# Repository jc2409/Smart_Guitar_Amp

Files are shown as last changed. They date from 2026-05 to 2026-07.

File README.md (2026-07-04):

# Smart Guitar Amp

Smart Guitar Amp Demo (https://www.youtube.com/watch?v=zBXpkTaCWV4)

A hybrid guitar-effect amplifier combining a hand-built analog signal chain, real-time
Arduino DSP firmware, and a browser-based control app. A player can dial in sounds
manually or describe a tone in natural language; the host translates that request into
validated firmware parameters and sends them to the board over USB serial.

Three working layers:

1. Analog hardware for guitar-level signal conditioning, optical gain control, ADC
   input conditioning, and PWM audio reconstruction.
2. Arduino firmware for real-time DSP, automatic gain control, serial commands, and
   telemetry.
3. A FastAPI + React web app with sliders, live telemetry, tuner display, OpenAI chat,
   and Whisper-based voice input.

The host falls back to a mock serial link when no board is connected, so the web app
and LLM/voice flow can be demonstrated without hardware.

## System Overview

```text
Guitar
  -> analog input buffer and 2.5 V bias
  -> optically controlled analog gain stage (VGA)
  -> 2nd-order Sallen-Key anti-aliasing LPF (fc = 7.2 kHz)
  -> Arduino A0 ADC (10-bit, 9615 Hz, free-running)
  -> ATmega328P DSP firmware (fixed-point, ISR-driven)
  -> 8-bit Fast PWM on pin 10 at 62.5 kHz
  -> two-stage RC reconstruction filter with op-amp buffer
  -> line / aux / high-impedance headphone output

Browser UI
  -> FastAPI host
  -> serial P frames to Arduino
  <- T telemetry frames from Arduino (~10 Hz)
  -> OpenAI chat and Whisper STT when enabled
```

The amp runs DSP on the bare-metal MCU; the browser, FastAPI host, and LLM steer
it over serial — without ever touching the real-time audio loop.

## Analog Signal Chain

The analog path runs entirely on a single 5 V rail. All audio rides a 2.5 V virtual
ground so the ATmega328P ADC sees a full bipolar swing without needing a split supply.

**Input stage — high-Z buffer and 2.5 V bias**

- R1 (10 kΩ) series input resistor gives a high-impedance front end (~MΩ with the
  op-amp) that will not load passive pickups.
- C1 (10 μF) AC-coupling cap blocks the guitar's DC, passing only the audio swing.
- A 2.5 V virtual-ground reference buffered by an LM358/MCP6002 (rail-to-rail,
  single-supply) centres the waveform for the ADC.

**Optocoupler VGA — silent analog gain control**

- The firmware drives an optocoupler LED from Timer1 PWM on pin 9 / OC1A.
- Light couples to an LDR (100 Ω–100 kΩ range), changing the analog gain without
  injecting any digital switching edges into the audio path.
- DC-free and click-free: resistance glides smoothly with no zipper noise or DC offset
  injection. Higher OCR1A = brighter LED = lower LDR resistance = lower gain.
- In automatic mode the firmware rides the VGA gently based on measured output peak:
  peak > 380 steps gain down, 8–40 steps gain up, < 8 (noise floor) never boosts,
  and silence drifts back to the resting value. One step per 15 ms gives a smooth
  ride with no pumping.

**Anti-alias filter and ADC**

- A 2nd-order Sallen-Key LPF (R = 10 kΩ, C = 2.2 nF, fc = 7.2 kHz) guards the ADC
  input. 7.2 kHz is well above the guitar's highest audible harmonic, so nothing
  musical is lost while aliasing is suppressed.
- ADC A0 runs free-running, prescaler 128 → ~9615 Hz sample rate (Nyquist 4.8 kHz).
- Prescaler 128 was chosen over 64: slower sampling doubles the 512-sample ring
  buffer's span to ~53 ms, maximising delay and reverb range, while 4.8 kHz Nyquist
  still covers the full guitar band.

**PWM audio output and reconstruction**

- Timer1 Mode 5 (8-bit Fast PWM, no prescaler) drives pin 10 / OC1B at 62.5 kHz.
- A two-stage passive RC chain (2.2 kΩ + 15 nF per pole) with an op-amp buffer between
  the stages attenuates the 62.5 kHz carrier by ~−44 dB while the guitar passband
  passes flat.
- The buffer-between-poles topology avoids the carrier feedthrough and slew-rate
  problems seen with a slow op-amp Sallen-Key stage.
- A 10 μF output coupling cap removes the 2.5 V DC bias; the HPF corner is ≈ 0.16 Hz,
  preserving full bass response. The output targets high-impedance line/aux inputs.
- 62.5 kHz was chosen so the carrier sits far above audio: a gentle two-pole passive
  RC can reject it fully. Trade-off: 10-bit→8-bit resolution (256 levels, ~48 dB SNR),
  which is adequate for guitar effects.

The PWM output-stage debugging and component choices are documented in
[src/PWM_Audio_Passthrough/DESIGN_NOTES.md](src/PWM_Audio_Passthrough/DESIGN_NOTES.md).

## Firmware

The current firmware is [src/DSP_Pipeline/DSP_Pipeline.ino](src/DSP_Pipeline/DSP_Pipeline.ino).
It targets an Arduino Uno R3 / ATmega328P.

**Real-time architecture**

Audio processing runs entirely in `ISR(ADC_vect)` — one DSP tick per sample at 9615 Hz
(~52 μs budget per sample). The ISR reads A0, subtracts the 2.5 V bias, runs one effect,
clips to ±511, shifts to 8-bit, and writes OCR1B. No float is used; every operation is
integer shifts and adds. Timer1's PWM hardware double-buffers OCR1B, so the 9615 Hz
ISR writes are glitch-free against the 62.5 kHz carrier.

Parameters are written by `loop()` atomically in a `cli/sei` block so the ISR never
reads a half-written parameter set. The 512-byte `int8_t` ring buffer holds ~53 ms
of history shared by delay, chorus, reverb, and tuner.

**Effects**

The firmware runs exactly one effect mode at a time:

| ID | Effect | Implemented behavior |
| --- | --- | --- |
| `0` | Clean | Transparent passthrough. |
| `1` | Overdrive | `driven = (x * drive) >> 4`, hard-clipped to ±511. `drive` 16 = edge of breakup, 180 = rock crunch, 480 = near square-wave metal. |
| `2` | Delay | One read-tap `delayLen` samples behind the write head; `feedback` regenerates the tail. Up to 512 samples (~53 ms slapback). |
| `3` | Chorus | Triangle-LFO modulated delay tap (depth 1–48 samples, rate 1–20 phase increments), 50/50 dry/wet, no feedback path. |
| `4` | Reverb | Ten fixed taps (73–487 samples, 7.6–50.7 ms) summed equally then fed back. Keep `feedback` < 205 for stability. |
| `5` | Tuner | Clean passthrough while `loop()` runs AMDF pitch detection every ~150 ms. |

**AMDF tuner**

The tuner computes D(τ) = Σ |buf[n] − buf[n+τ]| over lags τ = 24…128 samples
(≈ 75–400 Hz). Parabolic interpolation around the deepest dip recovers sub-sample
resolution — essential for the high strings, where one whole-sample lag step spans
tens of cents at 9615 Hz. A peak-amplitude gate suppresses readings on silence.
Pitch is reported as deci-Hz (Hz × 10) in the telemetry frame; the UI maps it to
the nearest standard-tuning string (E A D G B E) with a flat↔sharp cents needle.

**Serial control protocol**

The host sends an atomic all-parameters frame:

```text
P,<effect>,<drive>,<delayLen>,<feedback>,<mix>,<depth>,<rate>,<autoVGA>,<gain>
```

Ranges enforced by the firmware and host models:

| Field | Range | Meaning |
| --- | --- | --- |
| `effect` | 0-5 | Clean, overdrive, delay, chorus, reverb, tuner. |
| `drive` | 1-511 | Overdrive gain/clipping intensity. |
| `delayLen` | 1-512 | Delay tap distance in samples. |
| `feedback` | 0-255 | Delay repeats or reverb decay. |
| `mix` | 0-255 | Wet level for delay/reverb. |
| `depth` | 1-48 | Chorus modulation depth in samples. |
| `rate` | 1-20 | Chorus LFO phase increment. |
| `autoVGA` | 0 or 1 | Enable automatic analog gain control. |
| `gain` | -1 or 0-255 | `-1` keeps/uses auto mode; 0-255 sets manual VGA PWM. |

The board reports telemetry every 100 ms:

```text
T,<effect>,<peak>,<vga>,<clip>,<rxErr>,<freqDeciHz>
```

`freqDeciHz` is only nonzero in tuner mode and is reported as Hz × 10. The host turns
this into the tuner display against standard guitar tuning.

More firmware-specific notes are in [src/DSP_Pipeline/README.md](src/DSP_Pipeline/README.md).

## Web App

The web app lives in [src/host](src/host). It is a single FastAPI backend serving a
React/Vite frontend.

**Backend responsibilities**

- Own the real `AmpLink` serial connection, or use `MockLink` when hardware is absent.
- Keep the authoritative `AmpParams` state.
- Validate and clamp all values before they reach the firmware.
- Serve `GET /api/state`, `POST /api/params`, `POST /api/chat`, `POST /api/transcribe`,
  and `GET /api/telemetry`.
- Load `.env` for serial port, OpenAI proxy, CA bundle, model names, and server host/port.

**Frontend responsibilities**

- Manual amp controls for effect selection and the relevant parameters.
- Live telemetry and connection state.
- Tuner UI driven by firmware pitch telemetry.
- Chat panel for natural-language tone requests.
- Voice input flow using the wake phrase `hey amp`, browser microphone capture, Whisper
  transcription, and then the same chat/tone path as typed messages.

**Tone engine**

- OpenAI is the default provider when `OPENAI_API_KEY` is set.
- `OPENAI_BASE_URL` supports enterprise proxy routing.
- `OPENAI_CA_BUNDLE` lets Python trust enterprise TLS certificates without disabling
  verification.
- `OPENAI_CHAT_MODEL` currently defaults to `gpt-5.5`; change it in `.env` if the proxy
  reports no regional capacity for that model.
- Anthropic is available as a fallback with `AMP_LLM_PROVIDER=anthropic` and
  `ANTHROPIC_API_KEY`.

The LLM is not allowed to send arbitrary firmware strings. It can only call the structured
`set_amp_params` tool, and those values are validated by the host before the serial frame
is emitted.

## Running The Web App

From the repository root:

```bash
cd src/host
make env
# edit .env: set OPENAI_API_KEY, OPENAI_BASE_URL if required, and AMP_PORT if needed
make install
make run
```

Then open `http://127.0.0.1:8000`.

Useful setup commands:

```bash
make port          # list serial devices and mark likely Arduino ports
make set-port      # write detected board to .env as AMP_PORT=...
make serial-perms  # temporary Linux permission fix for the selected AMP_PORT
make doctor        # print local Python/Node/npm/OpenAI/AMP_PORT status
make web-dev       # frontend hot reload on :5173 while make run serves the API
make flash         # compile/upload firmware with arduino-cli
```

Dependencies and configuration are documented in [src/host/README.md](src/host/README.md).
The Python dependency lists are [src/host/requirements.txt](src/host/requirements.txt) and
[src/host/pyproject.toml](src/host/pyproject.toml); frontend dependencies are in
`src/host/web/package.json` and `src/host/web/package-lock.json`.

## Repository Layout

```text
data/                         images and schematics
src/DSP_Pipeline/             current Arduino DSP firmware and firmware README
src/PWM_Audio_Passthrough/    PWM output-stage prototype and final design notes
src/host/                     FastAPI backend, React frontend, Makefile, host docs
```

## Current Limitations

- Audio quality is constrained by the Arduino Uno ADC rate, 8-bit PWM output, SRAM, and
  simple reconstruction filter. This is a working guitar-effect prototype, not a studio
  audio interface.
- Only one firmware effect runs at a time (no chaining, e.g. overdrive + delay).
- The output stage expects a high-impedance input/load.
- Delay/reverb are limited to ~53 ms by the on-chip SRAM; external SRAM would extend this.
- Voice transcription and chat depend on the selected OpenAI model being available through
  the configured proxy and VPN policy.

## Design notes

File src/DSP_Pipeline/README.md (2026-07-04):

# Real-Time Guitar DSP Pipeline — Firmware

Arduino Uno R3 (ATmega328P) firmware implementing a real-time, **selectable
multi-effect** guitar DSP — **Clean / Overdrive / Delay / Chorus / Reverb** — plus
a **Tuner** mode that detects the played string's pitch, all with a serial command
interface for live parameter control.

Sketch: [`DSP_Pipeline.ino`](DSP_Pipeline.ino)

> **Note:** an earlier version of this firmware (and this README) ran a *cumulative*
> `Clip → Biquad EQ → Delay` pipeline driven by an `S,...` frame at 19230 Hz. That is
> obsolete. The current firmware selects **one** effect at a time and runs the ADC at
> **~9615 Hz**. The host software (`../host/`) targets this current protocol.

---

## Signal path

```
guitar (biased 2.5 V) ─▶ A0 ─▶ ADC (free-running, 10-bit, ~9.615 kHz, prescaler 128)
                                  │
                                  ▼  ISR(ADC_vect)   ← one DSP tick per sample
                    one of: Clean | Overdrive | Delay | Chorus | Reverb
                                  │
                                  ▼
                    OCR1B (8-bit, 62.5 kHz Fast PWM, pin 10)
                                  │
                                  ▼
                    RC reconstruction filter ─▶ analog audio out
```

- **Input**: guitar AC-coupled and biased to 2.5 V on A0; ADC reads 0..1023 (512 = silence).
- **Output**: pin 10 (OC1B), 8-bit Fast PWM, 62.5 kHz carrier, smoothed by an external RC filter.
- **Optocoupler**: pin 9 (OC1A), same Timer1, sets the analog VGA gain via the LED/LDR.
- **Sample rate**: ADC prescaler 128 → ~9615 Hz (Nyquist 4.8 kHz, matching the anti-alias LPF).
  Delay/reverb taps are `t = samples / 9615 Hz`; the 512-sample buffer holds ~53 ms.

---

## Effects

All processing is **fixed-point** (no float in the ISR). Samples are carried as
signed values centred on 0 (range −512..+511). **One effect is active at a time**
(selected with `e`); switching effects clears the audio ring buffer.

| ID | Effect | What it does | Parameters |
|----|---|---|---|
| 0 | **Clean** | Transparent passthrough | — |
| 1 | **Overdrive** | Pre-amplify then hard-clip | `thresh` 1..511 (drive: 16=breakup, 180=rock, 480=metal) |
| 2 | **Delay** | Single echo with feedback (~53 ms max) | `delayLen` 1..512, `feedback` 0..255, `mix` 0..255 |
| 3 | **Chorus** | Triangle-LFO modulated short delay, 50/50 dry/wet | `depth` 1..48, `rate` 1..20 |
| 4 | **Reverb** | Ten-tap feedback network | `feedback` 0..255 (keep < 205), `mix` 0..255 |
| 5 | **Tuner** | Clean passthrough + fundamental-pitch detection (reported via telemetry) | — |

**Delay/reverb timing**: `t = samples / 9615 Hz`. The 512-sample `int8` line holds ~53 ms.

### Tuner

Selecting **Tuner** (effect 5) passes the signal through clean while detecting the
played string's fundamental frequency and reporting it in the `freq` telemetry
field (deci-Hz; `0` = no pitch). The host UI shows the detected pitch against the
six standard-tuning strings (E2 A2 D3 G3 B3 E4) with a flat↔sharp cents needle.

- **Method**: **AMDF** (Average Magnitude Difference Function) over the audio ring
  buffer, searching lags ~24..128 samples (≈75–400 Hz). The deepest dip is the
  period; **parabolic interpolation** around it recovers sub-sample resolution —
  essential for the high strings, where one whole-sample lag step is tens of cents
  at 9615 Hz. A peak-amplitude gate suppresses readings on silence.
- **Where it runs**: in `loop()` (every ~150 ms), **not** the ISR, and only while
  effect 5 is active — so it costs nothing in the other modes. It works on a frozen
  copy of the most recent samples, since the ISR keeps overwriting the live ring
  during the (tens-of-ms) computation.

---

## Serial command interface

`115200 baud`, one command per line. The parser buffers a full line then parses
it (robust to `\n` / `\r\n` / no line ending).

| Command | Example | Effect |
|---|---|---|
| `e<0..5>` | `e1` | Select effect (0=clean 1=overdrive 2=delay 3=chorus 4=reverb 5=tuner) |
| `c<1..511>` | `c180` | Overdrive drive (thresh) |
| `d<1..512>` | `d400` | Delay length in samples |
| `f<0..255>` | `f190` | Delay/reverb feedback / decay |
| `m<0..255>` | `m220` | Delay/reverb wet mix |
| `r<1..48>` | `r24` | Chorus depth |
| `s<1..20>` | `s8` | Chorus LFO rate |
| `v<0\|1>` | `v1` | Auto-VGA on/off |
| `g<0..255>` | `g20` | Manual VGA gain (OCR1A); turns auto-VGA off |
| `x` | `x` | Bypass (clean passthrough) |
| `P,...` | `P,1,180,400,190,220,24,8,1,-1` | Atomic set-all frame (host link) |

The single-letter commands are for manual testing; the host uses the `P` frame.

> **Note**: a delay/echo is only audible on *transient* material (real guitar,
> plucks, music). On a steady sine it just produces inaudible comb filtering.

## Two-way host protocol (MCU ↔ PC)

Structured parameters in, status telemetry out. The host applies a whole preset
atomically with one `P` frame and reads `T` telemetry back:

```
PC -> MCU : P,<effect>,<drive>,<delayLen>,<feedback>,<mix>,<depth>,<rate>,<autoVGA>,<gain>\n
MCU -> PC : T,<effect>,<peak>,<vga>,<clip>,<rxErr>,<freq>\n      (emitted ~10 Hz)
```

- **`P` frame** — sets the entire parameter bank in one `cli/sei` section (no
  transient old+new mix), clearing the audio buffer on effect change. `gain` field
  `< 0` leaves the VGA untouched and honours the `autoVGA` flag; `>= 0` sets a manual
  gain and turns auto-VGA off. Malformed frames are rejected and counted in `rxErr`.
- **`T` telemetry** — `effect` (active effect ID), `peak` (max |output| since last
  report — a VU meter), `vga` (current `OCR1A`), `clip` (clipped since last report),
  `rxErr` (malformed-frame count), `freq` (detected fundamental in **deci-Hz** —
  Hz×10 — in tuner mode, else `0`).
  > The `freq` field is appended; the host parser accepts both the 6-field
  > (pre-tuner) and 7-field frames, so older firmware still parses.

### Host software

The full interface is the **web app** in [`../host/`](../host/) (FastAPI + LLM tone
engine + browser dashboard). For bench testing without a browser:

```bash
cd ../host && uv sync          # or: pip install -e .
python sf4_serial.py --demo overdrive
python sf4_serial.py --effect reverb --feedback 190 --mix 220
```

It builds a validated `AmpParams`, serialises the `P` frame, sends it, then prints
parsed `T` telemetry as a live meter.

---

## Architecture / timing

- **Timer1** — Mode 5, 8-bit Fast PWM, no prescaler → **62.5 kHz** carrier on
  OC1A (pin 9) and OC1B (pin 10). Pure hardware; **no overflow ISR**.
- **ADC** — free-running, `/128` prescaler → ~**9615 Hz** sample rate, with the
  conversion-complete interrupt enabled (Nyquist 4.8 kHz, matching the anti-alias LPF).
- **`ISR(ADC_vect)`** — the single DSP tick: reads `ADC`, runs `processEffect`,
  writes `OCR1B = result >> 2` (10-bit → 8-bit). Fires once per sample (~9615 Hz).
  Reading `ADC` clears `ADIF` and the ADC auto-restarts, so no flag handling is needed.
- `OCR1B` is **double-buffered** by the PWM hardware (latches at carrier BOTTOM),
  so updating it at 9615 Hz while the carrier runs at 62.5 kHz is glitch-free.
- **Parameter bank** — one `volatile Params` struct (`P`). `loop()` updates it
  atomically inside `noInterrupts()/interrupts()` (field-wise copies, because a
  `volatile` struct can't use the implicit copy ctor), so the ISR never reads a
  half-written parameter set.

---

## Testing & operation notes

### Reading the telemetry (`T,effect,peak,vga,clip,rxErr,freq`)
- **`effect`** — active effect ID (0–5).
- **`peak`** — loudest **post-effect** sample since the last report (~100 ms), as a
  centred magnitude. This is a live VU/level meter; it wobbles ±1 on a steady signal
  (normal). It reflects what the listener actually hears (the AGC rides off it), so
  it tracks the output, not the raw input.
- **`vga`** — current `OCR1A` (the optocoupler LED duty / analog gain); static until
  changed or moved by auto-VGA.
- **`clip`** — 1 if the signal hit the clip threshold in that window, else 0.
- **`rxErr`** — malformed-frame count; should stay 0 (link health).
- **`freq`** — detected fundamental in **deci-Hz** (Hz×10) in tuner mode, else `0`.

### Startup transient is expected (and repeats every run)
Opening the serial port toggles **DTR, which hardware-resets the Uno** — so every
`sf4_serial.py` run reboots the board from scratch. At boot `OCR1A = 20`
(resting VGA gain), then the first host `P` frame confirms auto-VGA mode; the optocoupler LDR
settles slowly (tens–hundreds of ms), so `peak` shows a brief spike that decays
(e.g. `197 → 6`). Harmless — it's the analog gain settling, not a glitch. Ignore
the first few telemetry lines, or add gain smoothing in firmware to remove it.

### What a sine-wave input can test
| Stage | Sine test | Method |
|---|---|---|
| Passthrough | ✅ | `x`; output = input, biased 2.5 V |
| Clipping (overdrive) | ✅ | drive above threshold → flat-topped wave + odd harmonics |
| Aliasing | ✅ | feed f > Nyquist (4.8 kHz) → watch it fold back |
| Delay comb | ✅ | sweep → notches every `FS/d` Hz |
| Chorus sweep | ✅ | slow LFO → pitch/comb notches drift up and down |
| Delay/reverb *echo* | ❌ | needs transients (real guitar / music) |
| Tuner | ✅ | feed a known tone → check `freq` (deci-Hz) telemetry |

### Signal levels (real guitar vs the VGA)
A raw passive guitar is weak and dynamic (~0.1–0.7 Vpp typical, peaks to ~1–1.5 Vpp
on hard strums, decaying fast) — it does **not** sit at line level. The optocoupler
**VGA (gain) is what boosts it** up to where `peak` crosses the clip threshold, so
`gain` (drive) + `clip_threshold` together behave like a pedal's Drive knob. On the
bench, ~1 Vpp from the generator is a *test* level to force clipping. Distortion is
naturally touch-sensitive: loud attack clips, decaying note cleans up.

---

## Implementation notes

### DSP runs in `ADC_vect`, not a timer ISR
The single DSP tick lives in **`ISR(ADC_vect)`** (~9615 Hz): it reads `ADC`, runs
`processEffect`, and writes `OCR1B`. The Timer1 overflow interrupt is left disabled
(`TIMSK1 = 0`) — the PWM carrier is pure hardware. Driving the DSP from the ADC
interrupt means it fires exactly once per sample, with no wasted firings.

### Atomic parameters from a `volatile` struct
`Params np = P;` / `P = np;` don't compile for a `volatile` struct, so `loop()`
copies fields one at a time inside `noInterrupts()/interrupts()`. This both satisfies
the compiler and makes parameter updates atomic — the ISR never sees a half-written
mix of old and new values, and switching effects clears the audio ring buffer.

### Robust serial parsing
The command parser **buffers a full line** then parses it with `atol` / `sscanf`,
tolerant of `\n`, `\r\n`, or no line ending. (An earlier `Serial.parseInt()` version
mis-read leftover `\r`/`\n` as `0`, e.g. `f160` → `feedback = 0`.) The board runs at
**115200 baud**; because the DSP no longer sits in a 62.5 kHz timer ISR, the USART RX
interrupt is serviced in time and there is no RX overrun.

### Two-way protocol (MCU ↔ PC)
The host applies a whole preset atomically with one **`P` frame** and reads **`T`
telemetry** back at ~10 Hz (`effect, peak, vga, clip, rxErr, freq`). The ISR tracks
`g_peak` / `g_clip` / `g_freqDeciHz`; `loop()` emits via `millis()`. The full
host-side link is the FastAPI web app in [`../host/`](../host/); `sf4_serial.py` is a
standalone CLI for bench testing the same `P`/`T` protocol.

---

## Recommended analog output stage

The PWM output needs an external reconstruction filter + buffer before any
external device. Drives high-impedance line inputs (Echo line-in, Sennheiser
Momentum 4 powered aux) directly — **no power amp needed**.

```
pin 10 ─[2-pole RC LPF: 2.2k / 15nF ×2]─ MCP6002 unity buffer ─ Rs 100Ω ─ Cout 10µF ─┬─ tip L ┐
                                                                                      ├─ tip R ┘ (tie, mono)
                                                                                     R 100k → GND
                                                                                      sleeve → GND
```

- **Use MCP6002** (rail-to-rail, single 5 V), **not** TL072 (needs ≥7 V).
- Because the MCP6002 is only 1 MHz GBW, **filter passively** (RC) and use the
  op-amp only as a buffer — do **not** put it in a Sallen-Key (it would leak the
  62.5 kHz carrier, like the LM358).
- Two RC poles give ~−40 dB at the carrier, removing the switching hash.
- `Cout` strips the 2.5 V DC bias; into a high-Z input the bass is preserved.

---

## Known limitations / potential issues

| Issue | Impact | Possible improvement |
|---|---|---|
| Hard-clip aliasing | Harsh "fizzy" distortion (folded harmonics) | Soft-clip lookup table; 2× oversampling |
| 8-bit PWM output | ~48 dB SNR; hiss on clean tones | Higher-res PWM; dithering |
| One effect at a time | No stacking (e.g. overdrive + delay) | Chain effects if CPU/SRAM allow |
| Delay/reverb ≤ ~53 ms | Slapback/short ambience, not long echo | External SRAM for a longer line |
| `int8` ring buffer | 2 LSBs dropped on stored samples | Wider buffer if SRAM allows |
| No parameter smoothing | Clicks on live LLM/host changes | Ramp parameters over a few ms |
| Free-running ADC jitter | Minor sample-timing noise | Timer-triggered ADC (needs a free timer) |
| 16 MHz AVR ceiling | Limited DSP headroom overall | Faster MCU for advanced effects |

---

## Status

Working lo-fi multi-effect demonstrator: selectable Clean / Overdrive / Delay /
Chorus / Reverb plus an AMDF Tuner, with live serial control **and a two-way MCU↔PC
link** (`P` params in, `T` telemetry out, at 115200). The FastAPI web app in
[`../host/`](../host/) drives this protocol from the browser, manual controls, and the
LLM tone engine; `sf4_serial.py` exercises the same link from the command line.

### Suggested next steps
- DSP quality: soft-clip lookup table (reduce overdrive aliasing), parameter/gain
  smoothing to remove clicks on live host changes.
- Longer delay/reverb via external SRAM, beyond the ~53 ms on-chip `int8` line.
- Build the MCP6002 analog output stage (above) for clean line-out.

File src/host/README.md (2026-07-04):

# Host - Backend, Voice UI, and Tone Engine

This directory contains the desktop/web host for the Smart Guitar Amp. One
FastAPI process owns the serial link to the Arduino, keeps the authoritative amp
state, runs the OpenAI-first tone engine, serves the React dashboard, and exposes
JSON/SSE APIs for manual control, chat, voice transcription, and telemetry.

## Layout

```text
app/
  main.py         FastAPI app: /api/* endpoints, static UI serving, app lifetime
  models.py       AmpParams, telemetry, chat schemas, firmware value ranges
  serial_link.py  hardware serial bridge, MockLink fallback, port autodetect
  tone_engine.py  OpenAI/Anthropic tone engine with set_amp_params tool use
  openai_client.py OpenAI client setup for API key, proxy URL, and CA bundle
  devtools.py     Makefile helpers for serial-port detection and config checks
  static/         built React UI generated by make web-build, gitignored
web/              React + Vite frontend source
sf4_serial.py     CLI bench-test tool for sending P frames and reading telemetry
Makefile          setup, build, run, serial, and firmware automation
requirements.txt  pip dependency list, kept in sync with pyproject.toml
pyproject.toml    Python project metadata and dependencies
.env.example      local configuration template; copy to .env
```

The React source lives in `web/`. `make web-build` compiles it into `app/static/`,
which FastAPI serves at `http://127.0.0.1:8000` by default.

## Quick Start

```bash
cd src/host
make env
# edit .env and set OPENAI_API_KEY, OPENAI_BASE_URL if using the Arm proxy,
# OPENAI_CA_BUNDLE if your machine needs the company CA, and SF4_PORT if needed
make install
make run
```

Open `http://127.0.0.1:8000`.

`make run` also installs Python dependencies and builds the UI on first run if the
built frontend is missing. Use `Ctrl+C` to stop Uvicorn.

## Make Targets

| Target | Purpose |
| --- | --- |
| `make help` | Print the available commands. |
| `make env` | Create `.env` from `.env.example` if it does not exist. |
| `make py-install` | Install backend dependencies with `uv sync` when `uv` is available, otherwise create `.venv` and run `pip install -r requirements.txt`. |
| `make web-install` | Install frontend dependencies with `npm ci --include=dev --no-audit --no-fund --progress=false`. |
| `make web-build` | Build the React/Vite UI into `app/static/`. |
| `make install` | Run backend install, frontend install, and frontend build. |
| `make run` | Start FastAPI on `HOST:PORT`, building the UI first if missing. |
| `make dev` | Same as `make run`, but with Uvicorn `--reload`. |
| `make web-dev` | Start Vite hot reload on port 5173; `/api` is proxied to FastAPI on port 8000. |
| `make port` | List detected serial ports and mark likely Arduino ports with `*`. |
| `make set-port` | Write the first likely Arduino port into `.env` as `SF4_PORT=...`. |
| `make serial-perms` | Temporarily run `sudo chmod a+rw $(SF4_PORT)` if Linux denies access to the board. |
| `make doctor` | Print Python, Node, npm, host URL, serial setting, and whether OpenAI settings are present. |
| `make cli ARGS="--demo overdrive"` | Test the serial link without the browser. |
| `make flash` | Compile and upload `../DSP_Pipeline` with `arduino-cli`. |
| `make clean` | Remove `.venv`, Python caches, and built UI output. |

For frontend-only development, use two terminals:

```bash
make run        # terminal A: FastAPI on :8000
make web-dev    # terminal B: Vite on :5173 with /api proxying
```

## Dependencies

System tools:

- Python 3.11 or newer.
- Node.js and npm for the React/Vite frontend.
- `arduino-cli` only if you want `make flash` to compile and upload firmware.
- Linux serial access to the board, either through group membership or `make serial-perms`.

Python packages are declared in both `requirements.txt` and `pyproject.toml`:

- `fastapi`, `uvicorn[standard]`: web server and API runtime.
- `pyserial`: USB serial link to the Arduino.
- `openai`, `httpx`: OpenAI chat/STT client, enterprise proxy, and CA-bundle support.
- `anthropic`: optional fallback provider.
- `pydantic`: API and firmware parameter validation.
- `python-dotenv`: `.env` loading.
- `python-multipart`: browser audio upload support for `/api/transcribe`.

Frontend packages are managed by `web/package.json` and `web/package-lock.json`.
Use `make web-install` or `make install`; do not use `npm install --omit=dev`, because
Vite is a dev dependency required for building.

## Configuration

Copy `.env.example` to `.env` with `make env`. `.env` is gitignored and should hold
machine-specific settings and API keys.

| Variable | Default | Meaning |
| --- | --- | --- |
| `SF4_LLM_PROVIDER` | `openai` | Tone engine provider: `openai` or `anthropic`. |
| `OPENAI_API_KEY` | blank | Required for OpenAI chat and Whisper transcription. |
| `OPENAI_CHAT_MODEL` | `gpt-5.5` | Chat model used for tone generation. Change this if the proxy has no capacity for that model. |
| `OPENAI_BASE_URL` | OpenAI default | Set to the enterprise proxy URL, for example `https://openai-api-proxy.geo.arm.com/api/providers/openai/v1`. |
| `OPENAI_CA_BUNDLE` | Arm root CA path | Optional CA bundle path for enterprise TLS verification. |
| `OPENAI_TRANSCRIBE_MODEL` | `whisper-1` | Speech-to-text model used by `/api/transcribe`. |
| `ANTHROPIC_API_KEY` | blank | Optional fallback when `SF4_LLM_PROVIDER=anthropic`. |
| `SF4_MODEL` | `claude-haiku-4-5` | Anthropic model name for the fallback provider. |
| `SF4_PORT` | auto-detect | Serial device, for example `/dev/ttyACM0`. Use `make port` or `make set-port`. |
| `HOST` / `PORT` | `127.0.0.1` / `8000` | Uvicorn bind address used by `make run` and `make dev`. |

For the Arm enterprise OpenAI proxy, the relevant `.env` entries are usually:

```bash
OPENAI_API_KEY=your_key_here
OPENAI_BASE_URL=https://openai-api-proxy.geo.arm.com/api/providers/openai/v1
OPENAI_CA_BUNDLE=/usr/local/share/ca-certificates/ARM-Enterprise-PKI-Root-CA.crt
OPENAI_CHAT_MODEL=gpt-5.5
OPENAI_TRANSCRIBE_MODEL=whisper-1
```

If you see `data_residency_mismatch` or `No available capacity`, the proxy rejected the
selected model in that region. Change `OPENAI_CHAT_MODEL` to a model that your proxy
supports and restart `make run`.

## API

| Endpoint | Purpose |
| --- | --- |
| `GET /api/state` | Current amp parameters, serialized with the effect name. |
| `POST /api/params` | Apply a full manual `AmpParams` update. |
| `POST /api/chat` | Run one tone-engine turn; may call `set_amp_params` and update the board. |
| `POST /api/transcribe` | Upload browser audio and return Whisper text. |
| `GET /api/telemetry` | Server-Sent Events stream of board telemetry at about 10 Hz. |

The app falls back to `MockLink` when no Arduino is available, so the UI, chat, and
voice flow can be tested without hardware. Manual changes still update the shared app
state, but no serial frames are sent to a board.

## Troubleshooting

- `vite: not found`: run `make web-install` or `make install`. If npm used omitted dev dependencies, run `npm --prefix web ci --include=dev --no-audit --no-fund --progress=false`.
- Npm hangs on VPN: check whether company VPN/proxy rules block `registry.npmjs.org`; disconnecting VPN or configuring npm proxy may be required.
- `Permission denied: /dev/ttyACM0`: run `make set-port`, then `make serial-perms`, or add your user to the Linux dialout group and log out/in.
- `Chat is unavailable`: set `OPENAI_API_KEY` or configure the Anthropic fallback, then restart the server.
- `Transcription error`: check `OPENAI_API_KEY`, `OPENAI_BASE_URL`, `OPENAI_CA_BUNDLE`, and VPN/proxy connectivity.
- Browser says microphone denied: allow microphone access for `http://127.0.0.1:8000` in the browser site settings, then reload.

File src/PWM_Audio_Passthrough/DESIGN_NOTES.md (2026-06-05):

# PWM Audio Passthrough — Design & Debug Notes

A record of the debugging session that took the PWM audio output from "looks like
raw PWM on the scope" to a clean, full-range guitar signal. Covers the filter
diagnosis, the component-value fixes, and the firmware change to a 62.5 kHz carrier.

---

## 1. The system

- **Arduino Uno R3**, guitar signal biased to 2.5 V into **A0** (ADC 0..1023, 512 ≈ silence).
- **Timer1 Fast PWM** drives two independent outputs:
  - **Pin 10 (OC1B)** → audio, through a low-pass filter → audio jack.
  - **Pin 9 (OC1A)** → optocoupler LED (VGA gain stage), set over serial.
- Audio recovered by averaging the PWM (low-pass) then AC-coupling out (high-pass).

Output analog chain (KiCad): `pin 10 → R12 → C7 (low-pass) → LM358 (U2B) → C8 → R13 (high-pass) → AudioJack`.

---

## 2. The symptom

On the PicoScope:
- **Blue (A)** = analog input at A0: a clean sine (300/600/800 Hz test tones), biased at 2.5 V.
- **Red (B)** = "recovered" output: a dense band of pulses, **cycle time 64.00 µs → 15.625 kHz**.

The red trace never looked like the blue sine. The user asked why.

### Why red ≠ blue (the concept)
The raw PWM is a **two-level carrier** (≈0 V or ≈5 V) switching at 15.625 kHz. The
audio is encoded in the **duty cycle / pulse width**, not the instantaneous voltage:

```
blue high (3.5V)  ->  OCR1B large  ->  pulses WIDE  (more time at 5V)
blue low  (2.0V)  ->  OCR1B small  ->  pulses NARROW (more time at 0V)
```

You recover the sine by taking the **running average** of the PWM — which is exactly
what the RC low-pass does. So red ≠ blue *before* the filter is expected and correct.

---

## 3. Root cause #1 — the low-pass filter wasn't filtering

A low-pass needs **both** the series resistor **and** the shunt cap to ground. R12
alone does nothing (the op-amp input is high-impedance, so almost no drop across R12).
C7 is the part that averages the pulses.

The cutoff:

$$f_c = \frac{1}{2\pi R C}$$

The board had **R12 = 1k** and **C7 marked `103` = 10 nF** (NOT the assumed 220 nF):

$$f_c = \frac{1}{2\pi \cdot 1000 \cdot 10\text{n}} \approx 15.9\ \text{kHz}$$

That sits **right on top of the 15.625 kHz carrier** → only −3 dB attenuation → the
carrier passes straight through. Time-constant view: `τ = R12·C7 = 10 µs`, but the
PWM period is `64 µs`, so the cap fully tracks each pulse instead of averaging.

### Capacitor code reminder (value in picofarads)
| Code | Value | Notes |
|---|---|---|
| `103` | 10 nF | what was in C7 (wrong — too small) |
| `104` | 100 nF | fc ≈ 1.6 kHz |
| `224` | 220 nF | fc ≈ 723 Hz |

> The user *thought* 220 nF was in C7, but `224` (220 nF) was actually in **C8**
> (the output coupling cap). So C7 = 10 nF (low-pass), C8 = 220 nF (coupling) —
> swapped roles.

### Fix
Put a real **220 nF (`224`)** in C7. With R12 = 1k → fc ≈ 723 Hz, carrier ≈ −27 dB.
The red trace then collapsed into a recognizable sine (with some residual ripple).

---

## 4. Root cause #2 — single RC can't cover guitar range AND reject the carrier

After the 220 nF fix, the recovered sine still had **high-frequency ripple** (residual
15.6 kHz carrier). The fundamental problem:

- **Guitar needs audio out to ~5 kHz** (fundamentals reach ~1.3 kHz; harmonics/tone to ~5–6 kHz).
- **Carrier is at 15.6 kHz** — only **~3× above** the audio top.
- A single-pole RC is just 20 dB/decade. To kill a carrier only 3× away you must drop
  fc so low it also eats the guitar harmonics. **You can't win with a filter alone.**

Single-pole trade-off table (R12 = 1k):

| C7 | Code | fc | Carrier rejection | Audio bandwidth |
|----|---|----|----|----|
| 220 nF | `224` | 723 Hz | −27 dB (~150 mV ripple) | ~720 Hz |
| 470 nF | `474` | 339 Hz | −33 dB | ~340 Hz (too dull) |
| 1 µF | `105` | 159 Hz | −40 dB | bass only ❌ |

---

## 5. The Sallen-Key attempt — and why it made things WORSE

We tried reusing the LM358 (U2B) as a **unity-gain Sallen-Key 2nd-order low-pass**
(Ra=Rb=2.2k, Ca=47 nF, Cb=22 nF). Result: **far worse** — big slew spikes,
channel over-range, and the dominant output frequency measured **~14.3 kHz** (carrier
feeding straight through).

Two reasons:

1. **LM358 is too slow.** ~1 MHz GBW, slew rate ~0.3 V/µs. At 15.6 kHz it has almost
   no loop gain and **slew-limits on the sharp PWM edges** → big spikes.
2. **Sallen-Key has inherent HF feedthrough.** The feedback cap **Ca connects the
   input-side node directly to the output**. At the carrier Ca ≈ 217 Ω (near short),
   so the raw PWM couples *around* the op-amp to the output. Above fc the rejection
   hits a floor instead of improving — and a slow op-amp makes it much worse.

**Lesson: do NOT use a Sallen-Key around the LM358 for this.** Either use a faster
op-amp (TL072 / MCP6002 rail-to-rail), or avoid the topology entirely.

---

## 6. The real fix — move the carrier away from the audio

The only way to have **full guitar bandwidth AND carrier rejection** is to stop
fighting the filter and **raise the PWM carrier** so a gentle filter at ~5 kHz works.

On a 16 MHz Uno, `carrier × resolution = 16 MHz`, so higher carrier = fewer bits:

| Carrier (Timer1 mode) | Resolution | Usable filter fc | Carrier rejection @ 5 kHz | Full guitar? |
|----|----|----|----|----|
| 15.6 kHz (10-bit, original) | 1024 | ~1.5 kHz max | — | ❌ loses harmonics |
| 31.25 kHz (9-bit) | 512 | 5 kHz | ~−32 dB (2nd order) | ✅ |
| **62.5 kHz (8-bit)** | 256 | **5 kHz** | **~−44 dB (2-stage RC)** | ✅✅ |

**Chosen: 8-bit / 62.5 kHz.** 256 levels (≈48 dB SNR) is fine for a guitar effect,
and the carrier is now ~12× above the audio top.

---

## 7. Recommended analog output chain (final)

Use the LM358 as a **plain buffer between two passive RC stages** (passive RC keeps
falling monotonically — no Sallen-Key feedthrough floor):

```
        ── LOW-PASS (sets top, kills carrier) ──    ── HIGH-PASS (sets bottom) ──
PWM ─R1─┬─→(+)LM358 buf─out─R2─┬─→ C8 ──┬──→ jack
        C1                     C2 nodeB  R13
        │                      │         │
       GND                    GND       GND
```

**Low-pass (per stage):**
- R1 = R2 = **2.2 kΩ**, C1 = C2 = **15 nF** (`153`) → fc ≈ 4.8 kHz each
- At 62.5 kHz: ~−22 dB per stage → **~−44 dB total**, monotonic, no spikes
- Passband flat to ~5 kHz → **full guitar tone preserved**
- **Buffer must sit BETWEEN the two stages** so they don't load each other (the
  op-amp's low output impedance isolates the poles).

**High-pass (strips the 2.5 V bias, sets the low end):**
- **C8 = 10 µF** (electrolytic) + R13 = 100 k → fc = 1/(2π·R13·C8) ≈ **0.16 Hz**
- Far below guitar low E (82 Hz) → **no bass loss**, with margin for low-Z loads.
- **Polarity matters:** `+` toward the op-amp side (~2.5 V), `−` toward the jack (0 V).

Resulting passband ≈ **0.16 Hz → 5 kHz** = full guitar range, carrier rejected.

### Capacitor dielectric note
For the filter caps, **film (polypropylene / polyester / polycarbonate)** beats Class II
ceramic (X7R/Y5V): tighter tolerance, no voltage-coefficient capacitance shift, and
lower distortion — so the filter corner stays put and the audio stays clean. (C8 stays
electrolytic for the bulk capacitance; it's outside the signal-shaping path.)

---

## 8. Firmware change (10-bit/15.6 kHz → 8-bit/62.5 kHz)

Edits applied to `PWM_Audio_Passthrough.ino`:

| Item | Before | After |
|---|---|---|
| Timer1 mode | Mode 7 (10-bit, `WGM11`+`WGM10`) | Mode 5 (8-bit, `WGM10` only) |
| Carrier | 16 MHz / 1024 = 15.625 kHz | 16 MHz / 256 = **62.5 kHz** |
| Audio scaling | `OCR1B = sample` (0–1023) | `OCR1B = sample >> 2` (0–255) |
| Mid-scale (silence) | `OCR1B = 512` | `OCR1B = 128` |
| Optocoupler range | `constrain(value, 0, 1023)` | `constrain(value, 0, 255)` |
| Serial help text | "0..1023" | "0..255" |

Key register block:

```c
// Timer1: Mode 5 = 8-bit Fast PWM (TOP = 0x00FF) on BOTH OC1A & OC1B
TCCR1A = (1 << COM1A1)   // non-inverting PWM on OC1A (pin 9, optocoupler)
       | (1 << COM1B1)   // non-inverting PWM on OC1B (pin 10, audio)
       | (1 << WGM10);   // WGM[11:10] = 01
TCCR1B = (1 << WGM12)    // WGM12 = 1 -> mode 5 (WGM[13:12] = 01)
       | (1 << CS10);    // no prescale -> 16 MHz / 256 = 62500 Hz

OCR1B  = 128;            // audio: mid-scale (2.5 V = silence)
OCR1A  = 0;             // optocoupler: LED off
```

ISR:

```c
ISR(TIMER1_OVF_vect) {        // fires at 62.5 kHz
  uint16_t sample = ADC;      // 0..1023 (512 = 2.5 V bias)
  // sample = processEffect(sample);   // DSP hook (passthrough for now)
  OCR1B = sample >> 2;        // scale 10-bit ADC -> 8-bit PWM (512 -> 128)
}
```

**Notes:**
- ADC unchanged (free-running 10-bit, ~19 kHz sample rate) — plenty for ~5 kHz audio.
  The PWM refreshes faster than the ADC updates, which is harmless.
- Optocoupler now takes **0–255**, not 0–1023 (update any host scripts).
- Don't use `analogWrite()` — the timer config has been replaced.

---

## 9. Quick reference — diagnostic checklist

If the recovered audio looks like raw PWM again:
1. **Is C7 actually the right value and soldered?** A series R with no shunt cap = no filter.
   Measure C7 with a multimeter on the capacitance range (or scope the op-amp + input).
2. **Decode the cap code:** `103` = 10 nF, `224` = 220 nF, `153` = 15 nF.
3. **Check fc vs carrier:** `fc = 1/(2π R C)` must be well below the carrier.
4. **Don't Sallen-Key the LM358** — passive RC + buffer instead.
5. **Carrier too close to audio?** Raise it in firmware (8-bit/62.5 kHz).
6. **Scope tip:** AC-couple channel B and pick a sensible range to see the ripple
   (the 2.5 V DC bias + spikes will over-range a tight DC window).

---

## 10. Driving the Sennheiser Momentum 4 (line-input mode)

**Connection assumption:** headphones powered **ON**, fed via the 2.5 mm aux cable.
In this mode you drive the headphones' **high-impedance aux/line input** (their own
internal amp drives the speakers). You do **NOT** drive the low-impedance drivers, so
**no headphone power amp is needed** — just deliver a clean, level-controlled,
DC-blocked, mono line signal.

### Design rule
Finish ALL filtering first, then present a **low-impedance, level-controlled output**.
Do not tap the signal from behind a series resistor. The LM358 is a **dual** op-amp, so
use its unused second half (U2A) as the final output buffer — no new chip required.

### Final output stage
```
   ── LP stage 1 ──    ── LP stage 2 ──    ── output buffer ──   ── level + DC block ──
PWM ─R1─┬─→(+)U2B─R2─┬─→(+)U2A──┬─Rout─┬─C8─┬── VR1 top
(pin10) │  (buffer)  │ (buffer) │  +   │    │   wiper ──→ TIP + RING (J6)
       C1        ┌──(−)        (−)─────┘    └── VR1 10k log
        │       C2          (− tied to out)        bottom ── GND
       GND       │           unity gain                          SLEEVE (J6) ── GND
                GND
```

### Component changes from the current single-stage board
| Ref | Now | Change to | Why |
|-----|-----|---|-----|
| R1 (was R12) | 1k | **2.2 kΩ** | LP stage 1, fc ≈ 4.8 kHz |
| C1 (was C7) | 10 nF (`103`) | **15 nF (`153`) film** | LP stage 1 |
| R2 | — | **add 2.2 kΩ** | LP stage 2 |
| C2 | — | **add 15 nF (`153`) film** | LP stage 2 |
| U2A | unused | wire as 2nd unity buffer | low-Z output |
| Rout | — | **add 220–470 Ω** | protect op-amp from cable/short |
| C8 | 220 nF | **10 µF electrolytic** | DC block (`+` toward op-amp) |
| VR1 | — | **add 10 kΩ log ("audio taper") pot** | volume / level match (safety!) |
| R13 | 100k | **remove** | the pot now provides C8's DC ground path |

### Critical wiring
1. **Tie TIP and RING together** at the jack. The effect is MONO; the headphones are
   STEREO. Tip-only = sound in one ear. T + R → pot wiper; **S → GND**.
2. **Volume pot:** signal → top, **wiper → jack (T+R)**, bottom → GND.
3. **Common ground** between Arduino GND and the jack sleeve; use shielded cable.

### Why keep the full two-stage filter even though the carrier is inaudible
Active ANC headphones **re-digitize the aux input** (ADC ~48 kHz). A 62.5 kHz carrier
residue would **alias** into the audible band as a whistle/noise. The two-stage filter
(~−44 dB at the carrier) prevents that. Don't drop the second RC stage.

### LM358 note
Output swings ~0 V to ~3.5 V (can't reach +5 V). Biased at 2.5 V, that's ~±1 V clean
swing — plenty for line level. Because the signal never crosses 0 V, the LM358's
crossover distortion is avoided (the one regime where it's acceptable for audio).

### If you ever need PASSIVE (low-impedance driver) drive instead
The LM358 can't do it. Add a current-capable headphone amp (NJM4556, PAM8908, TPA6132)
and a much larger coupling cap (~220–470 µF for 32 Ω, else the bass is gutted).

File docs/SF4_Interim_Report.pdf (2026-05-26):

## SF4: Data Logger – Interim Design Report

Smart Guitar Effects Processor & Data Logger

Name(s): Gijeong Lee, Jaehyung Choi CRSid(s): gl534, jc2409
Group No.: 3
Date: May 26, 2026

### 1 Introduction & Application Specification

The primary objective of this project is to develop an advanced embedded system utilising the Arduino Uno hardware platform (powered by the ATmega328P MCU) configured as an interactive Smart Guitar Effects Processor and Data Logger. This directly addresses the requirement to specify an application demonstrating two-way communication between the MCU and PC. A user submits natural-language tone requests (e.g. “Make me sound like David Gilmour”) via a web interface; an LLM translates these into structured DSP parameter JSON payloads that are streamed to the MCU, which returns status/telemetry back to the PC over the same serial link.

### 2 Conceptual System Design & Communications

The system architecture is strictly partitioned into three specialised operational environments: Analogue Circuitry, Arduino UNO R3 Firmware, and Host PC Software. The block diagram below illustrates the full signal path and bidirectional JSON payload exchange over the 115200 Bd USB Serial Bridge. PC-to-MCU frames carry DSP coefficients (biquad b0–a2, clip threshold, delay length, PWM duty); MCU-to-PC frames return a compact status packet (clip indicator, current gain, buffer health).

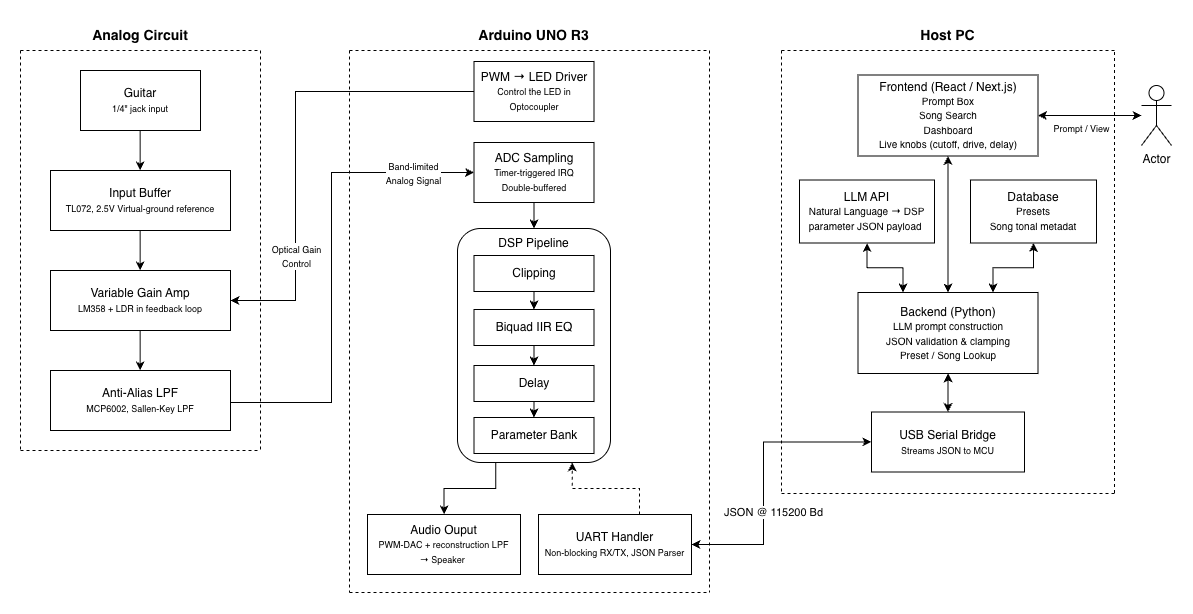
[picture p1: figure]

Figure 1: Systems and Communications Block Diagram.

### 3 Detailed Hardware Design

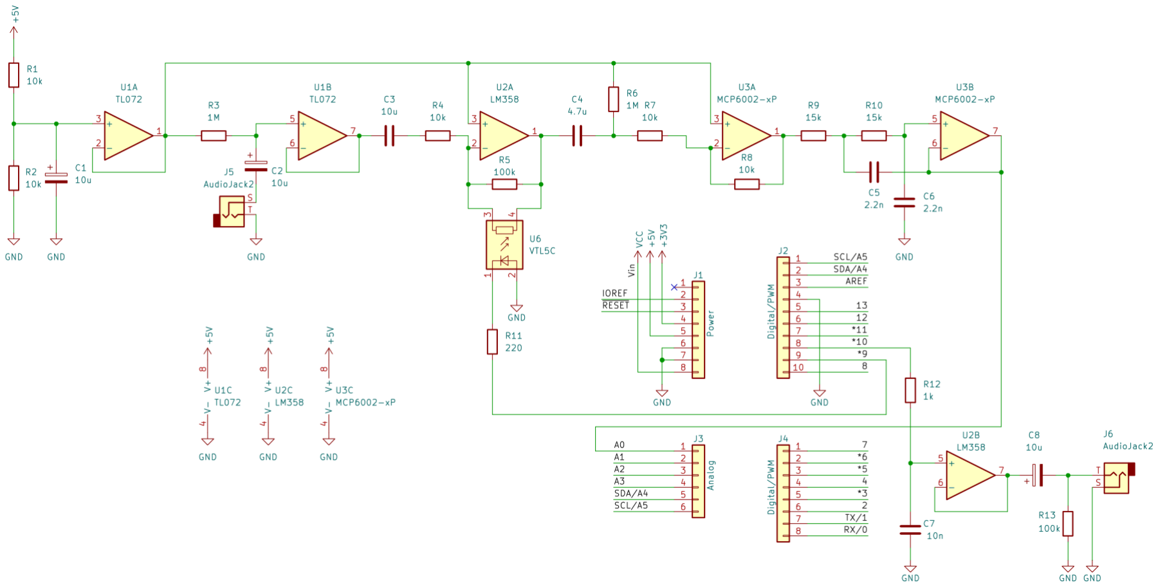
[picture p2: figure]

Figure 2: Analogue Circuit Design Schematic (KiCad).

All sub-circuits were unit-tested in LTSpice before integration (see Appendix 6). Stage 1 (Input Buffer): TL072 JFET op-amp with 1 MΩ input impedance; second channel buffers a R1/R2 divider to produce a 2.5 V virtual-ground reference. Stage 2 (Variable Gain Amplifier): LM358 inverting amplifier with an NSL-32SR3 optocoupler LDR in the feedback path; firmware PWM controls the LED to set gain optically, isolating the audio path from digital noise. Simulation confirms variable gain across RLDR = 100 Ω–100 kΩ. Stage 3 (Anti-Aliasing LPF): MCP6002 Sallen-Key LPF (R = 15 kΩ, C = 2.2 nF, fc ≈ 4.8 kHz), satisfying the Nyquist criterion for 20 kHz ADC sampling. Audio Output: the Arduino PWM DAC output is fed into an RC reconstruction filter (LM358, R = 1 kΩ, C = 33 nF) which integrates the switching waveform into a smooth analogue sinusoid, then AC-coupled via 10 µF to the speaker load.

### 4 Firmware & Software Implementation Plan

The firmware architecture circumvents standard blocking Arduino function libraries to sustain low-latency real-time audio operations, utilising Timer1 interrupts at 20 kHz (50 µs period) for ADC triggering. The Host PC software utilises a React/Next.js frontend and Python/FastAPI backend to handle LLM-driven JSON parameter generation.

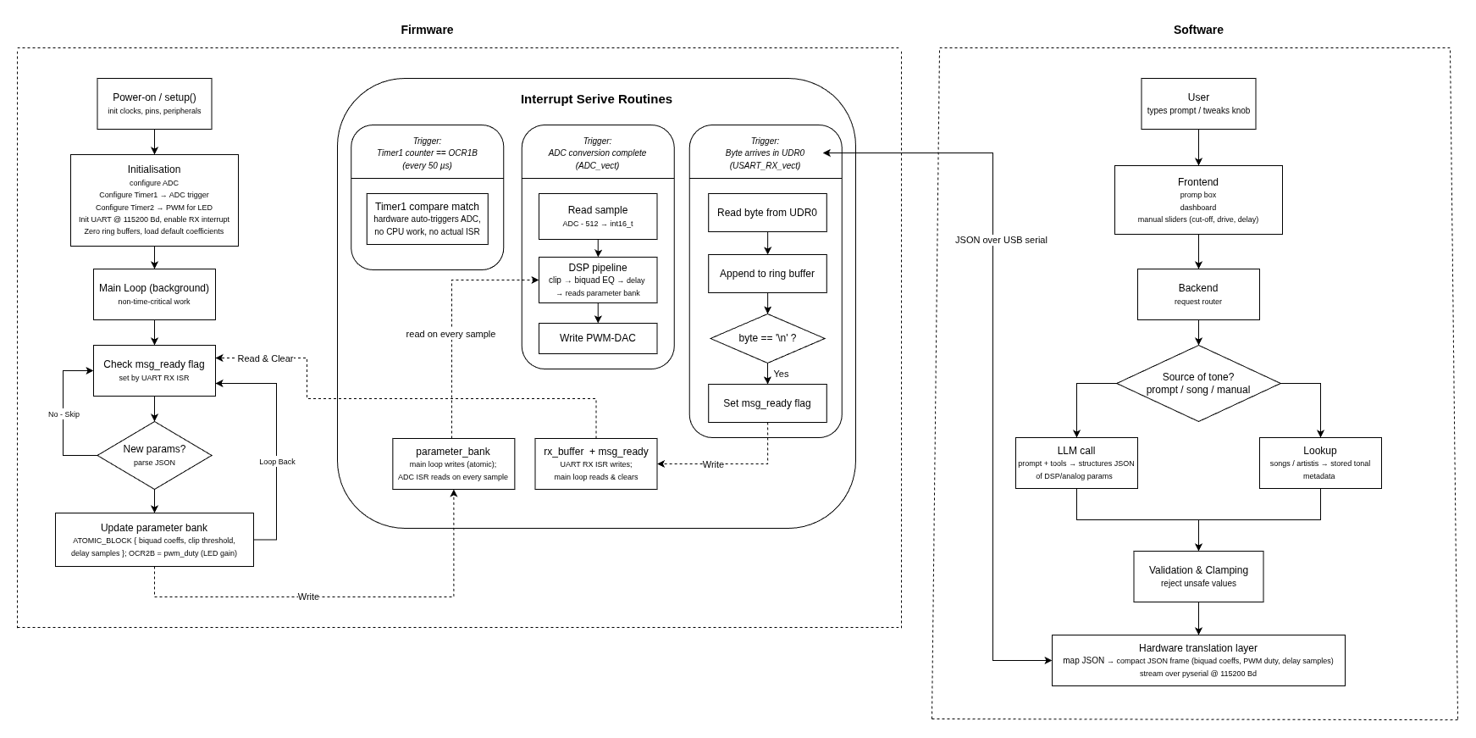
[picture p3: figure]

Figure 3: Firmware and Software Flow Diagram.

### 5 Component Requirements & Parts List

To assemble the target custom prototype circuit board, components have been selected within the strict £15.00 project budget limit.

Table 1: Parts List for Purchasing (BOM)

Order Code | Brief Component Description | Qty | Unit Price (£) Total (£)
SC17220 | JFET-Input Dual Op-Amp (TL072CP) | 1 | 1.000 | 1.000
SC17198 | Dual Low-Power Op-Amps (LM358AP) | 1 | 0.370 | 0.370
1292245 | Rail-to-Rail Dual Op-Amp (MCP6002-I/P) | 1 | 0.346 | 0.346
3692218 | Optocoupler / Vactrol (NSL-32SR3) | 1 | 3.290 | 3.290
CN23320 | 6.35mm (1/4”) PCB Mono Jack Socket | 1 | 0.930 | 0.930
CN22697 | 3.5mm Stereo Panel Jack Socket | 1 | 0.330 | 0.330
Total Custom Expenditure (Budget: £15.00) | £6.266

### 6 Work Allocation

To optimise execution efficiency across the remaining two-week timeline, work tasks are divided as follows:
- Gijeong Lee (CRSid: gl534): Primary ownership of hardware and full-stack software; responsible for breadboarding the analogue front-end, testing the Sallen-Key LPF and VGA stages, calibrating optocoupler gain metrics, and building the Host PC software stack comprising the React/Next.js frontend (prompt UI, dashboard, manual sliders), Python/FastAPI backend (LLM prompt construction, JSON validation), and Supabase database (preset and song tonal metadata storage).
- Jaehyung Choi (CRSid: jc2409): Primary ownership of firmware and hardware–software communication; responsible for register-direct Timer1 ADC triggering, the real-time biquad/clipping/delay DSP pipeline, nonblocking UART interrupt handlers, and the PC-side hardware translation layer (pyserial scripts that serialise validated JSON payloads and parse incoming MCU status packets).

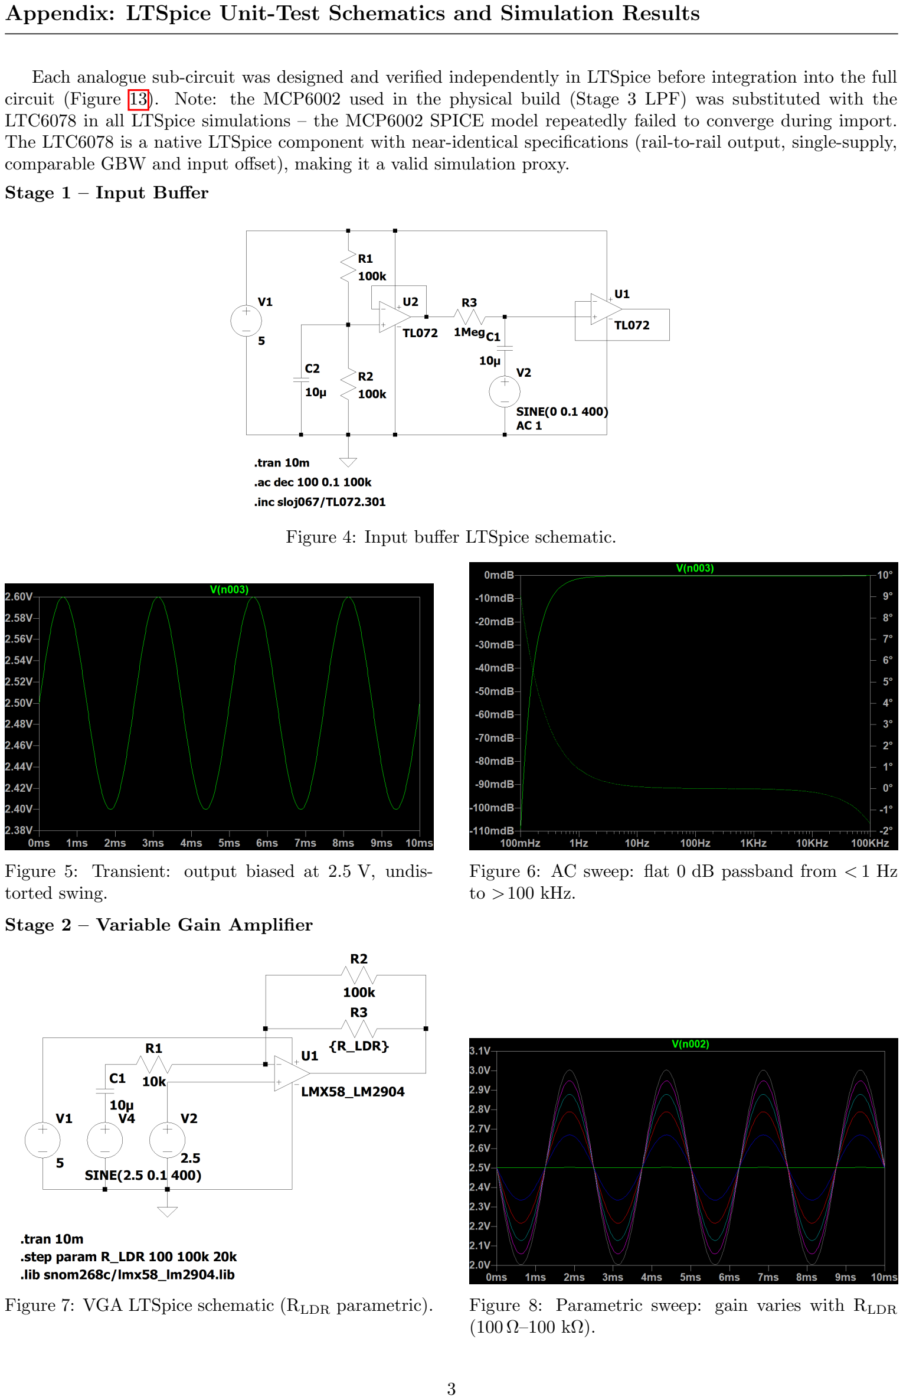
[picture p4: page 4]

Appendix: LTSpice Unit-Test Schematics and Simulation Results

Each analogue sub-circuit was designed and verified independently in LTSpice before integration into the full circuit (Figure 13). Note: the MCP6002 used in the physical build (Stage 3 LPF) was substituted with the LTC6078 in all LTSpice simulations – the MCP6002 SPICE model repeatedly failed to converge during import. The LTC6078 is a native LTSpice component with near-identical specifications (rail-to-rail output, single-supply, comparable GBW and input offset), making it a valid simulation proxy.

Stage 1 – Input Buffer

Figure 4: Input buffer LTSpice schematic.

Figure 5: Transient: output biased at 2.5 V, undistorted swing.

Figure 6: AC sweep: flat 0 dB passband from < 1 Hz to >100 kHz.

Stage 2 – Variable Gain Amplifier

Figure 7: VGA LTSpice schematic (RLDR parametric). Figure 8: Parametric sweep: gain varies with RLDR (100 Ω–100 kΩ).

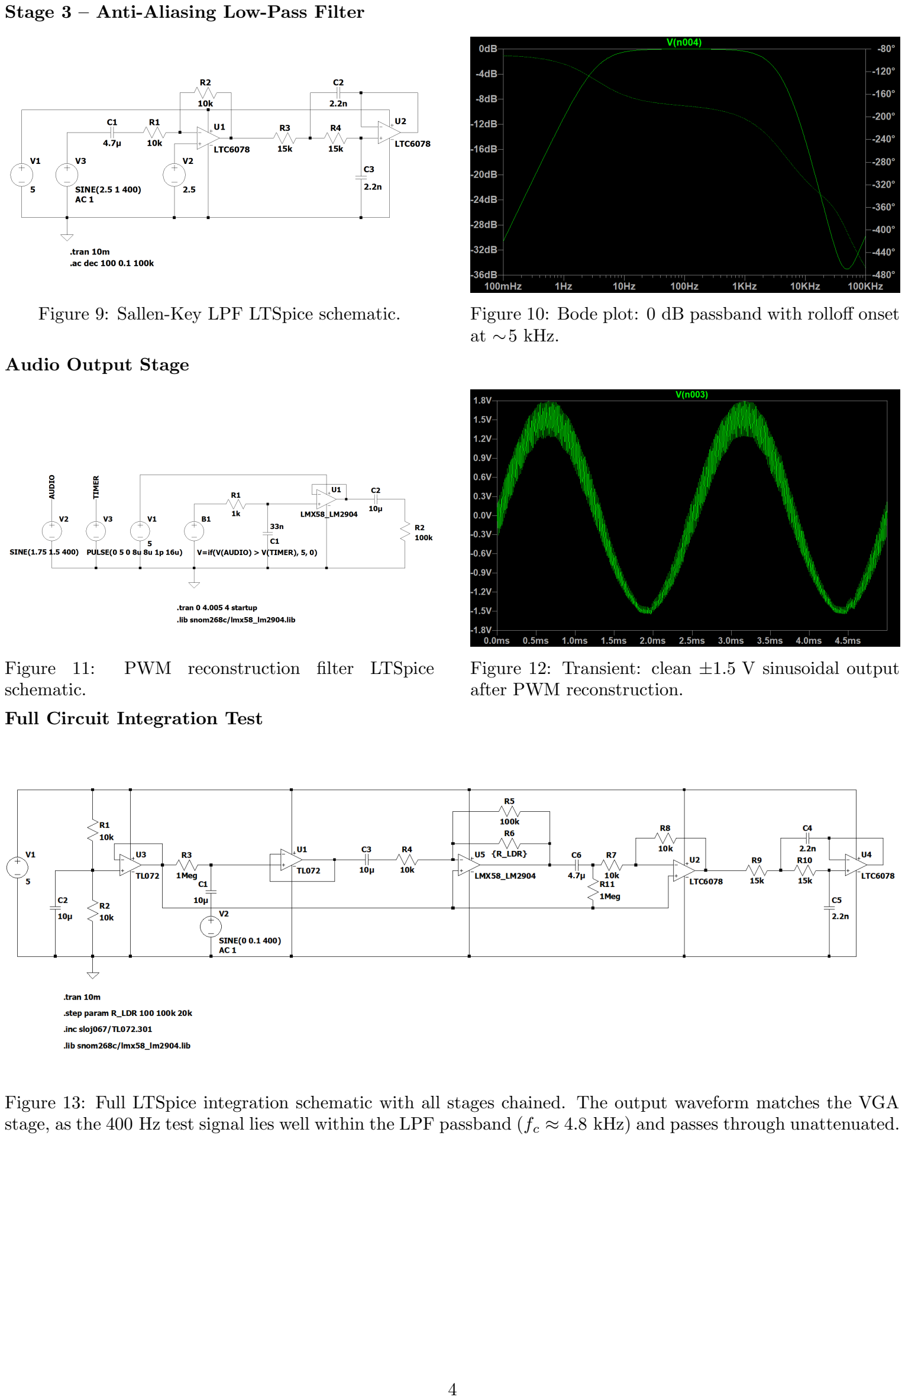
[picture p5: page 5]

Stage 3 – Anti-Aliasing Low-Pass Filter

Figure 9: Sallen-Key LPF LTSpice schematic. | Figure 10: Bode plot: 0 dB passband with rolloff onset at ∼5 kHz.

Audio Output Stage

Figure 11: PWM reconstruction filter LTSpice schematic.

Figure 12: Transient: clean ±1.5 V sinusoidal output after PWM reconstruction.

Full Circuit Integration Test

Figure 13: Full LTSpice integration schematic with all stages chained. The output waveform matches the VGA stage, as the 400 Hz test signal lies well within the LPF passband (fc ≈ 4.8 kHz) and passes through unattenuated.

Cambridge University Engineering Department Engineering Tripos Part IIA PROJECTS: Interim and Final Report Coversheet

TO BE COMPLETED BY THE STUDENT(S)

Project:

Title of report: | Group Report / Individual Report (delete as appropriate)
Name(s): (capitals) | crsID(s): | College(s):

Declaration for: Interim Report 1 / Interim Report 2 / Final Report (delete as appropriate)

I/we confirm that, except where indicated, the work contained in this report is my/our own original work.

Instructions to markers of Part IIA project reports:

Grading scheme

Grade | A* | A | B | C | D | E
Standard | Excellent | Very Good | Good | Acceptable | Minimum acceptable for Honours | Below Honours

Grade the reports by ticking the appropriate guideline assessment box below, and provide feedback against as many of the criteria as are applicable (or add your own). Feedback is particularly important for work graded C-E. Students should be aware that different projects and reports will require different characteristics.

Penalties for lateness: Interim Reports: 3 marks per weekday; Final Reports: 0 marks awarded – late reports not accepted.

Guideline assessment (tick one box)

A*/A | A/B | B/C | C/D | D/E
Marker: | Date:

Delete (1) or (2) as appropriate (for marking in hard copy – different arrangements apply for feedback on Moodle):

(1) Feedback from the marker is provided on the report itself.
(2) Feedback from the marker is provided on second page of cover sheet.

# IIA Projects

Typical Criteria | Feedback comments
| Appreciation of problem, and development of ideas
Project
Skills,
Initiative,
Originality
Competence in planning and recordkeeping

Practical skill, theoretical work, programming

Evidence of originality,
innovation, wider reading (with full referencing), or additional research

Initiative, and level of supervision required

Report

Overall planning and layout, within set page limit

Clarity of introductory overview and conclusions

Logical account of work, clarity in discussion of main issues

Technical understanding,
competence and accuracy

Quality of language, readability, full referencing of papers and other sources

Clarity of figures, graphs and tables, with captions and full referencing in text

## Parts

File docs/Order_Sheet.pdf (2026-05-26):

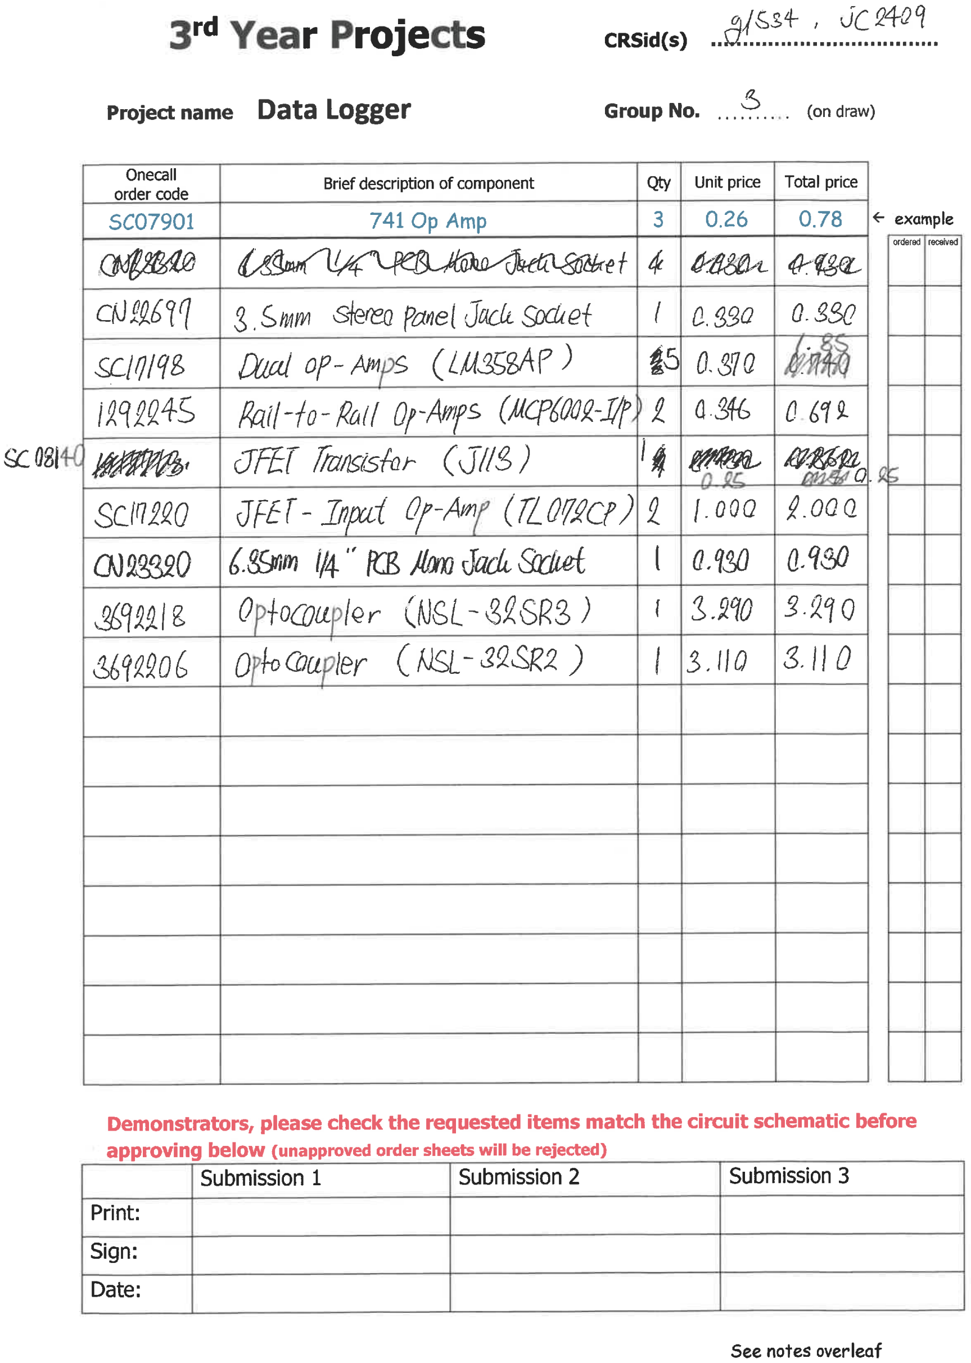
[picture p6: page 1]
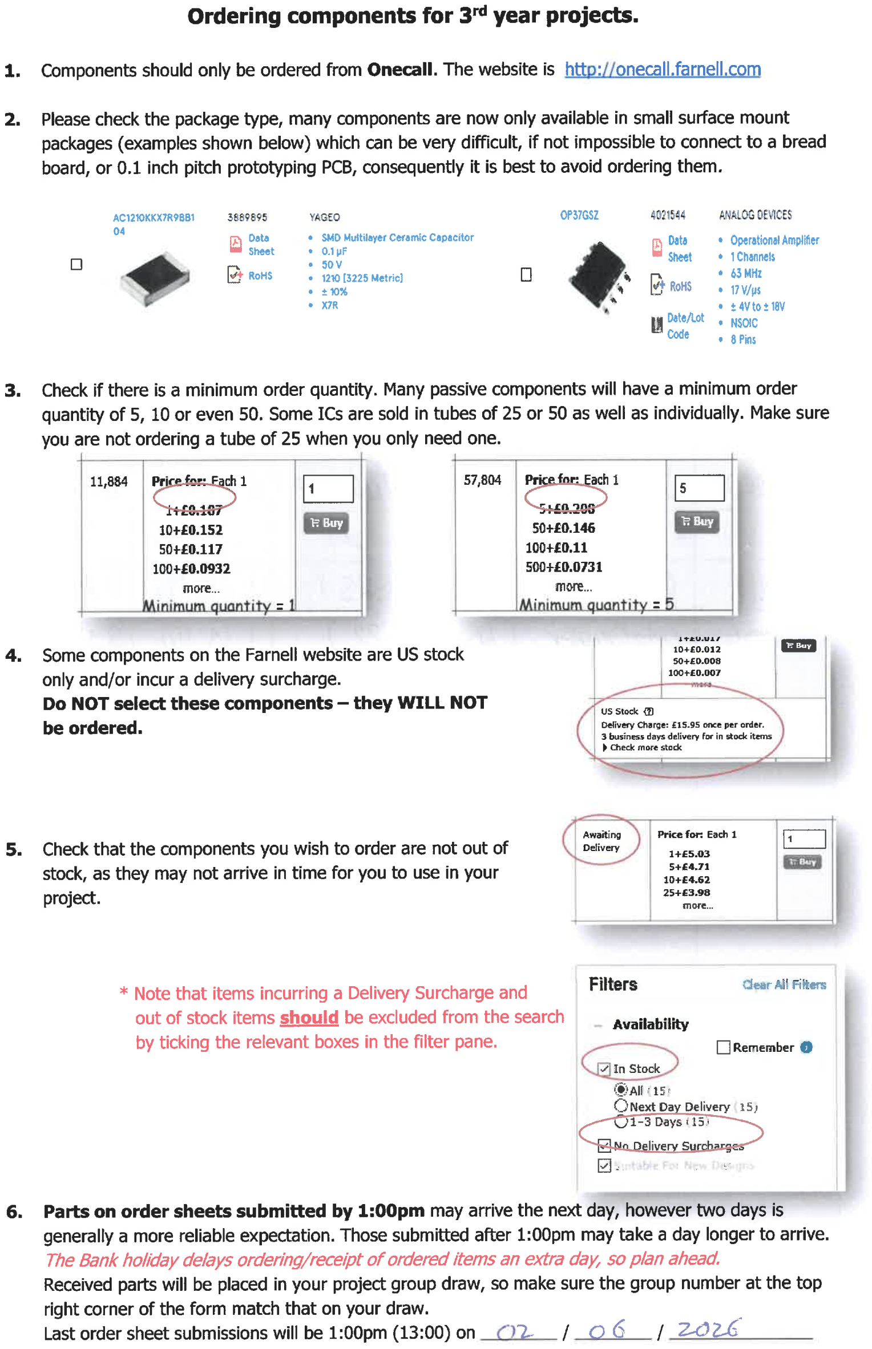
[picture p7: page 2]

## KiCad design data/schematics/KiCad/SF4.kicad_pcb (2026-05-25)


Board: 2 copper layers, 68.6 x 53.3 mm, 8 parts (0 on the bottom side), 3 nets, no tracks yet.

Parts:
J1: Power; PinSocket_1x08_P2.54mm_Vertical
J2: Digital/PWM; PinSocket_1x10_P2.54mm_Vertical
J3: Analog; PinSocket_1x06_P2.54mm_Vertical
J4: Digital/PWM; PinSocket_1x08_P2.54mm_Vertical
MH1, MH2, MH3, MH4: MountingHole_3.2mm

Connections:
/SCL/A5: J2.1, J3.6
/SDA/A4: J2.2, J3.5
GND: J1.6, J1.7, J2.4

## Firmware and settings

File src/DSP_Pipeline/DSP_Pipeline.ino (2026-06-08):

/*
 * Arduino Uno R3 — Real-time guitar DSP
 *
 * Effects (select with 'e' command):
 *   0 = Clean      — transparent passthrough
 *   1 = Overdrive  — hard clipping
 *   2 = Delay      — single echo with feedback (~53 ms max)
 *   3 = Chorus     — triangle-LFO modulated short delay, 50/50 dry/wet
 *   4 = Reverb     — five-tap feedback network
 *
 * VGA (pin 9 / OC1A): gradual soft-limiter when too loud; gentle boost when
 *   too quiet but above the noise floor; drifts back to resting gain otherwise.
 *   Higher OCR1A = lower gain (optocoupler: brighter LED -> lower R_LDR).
 *
 * Shared audio ring buffer: 512 x int8_t = 512 B SRAM.
 *   Samples stored right-shifted by 2 (2 LSBs lost; matches 8-bit PWM output).
 *
 * ADC  : A0, free-running, prescaler 128 -> FS ~= 9.6 kHz
 *         Nyquist = 4.8 kHz, matches the analog anti-aliasing LPF cutoff exactly.
 *         Lower FS doubles the max delay/reverb time vs prescaler 64.
 * PWM  : pin 10 / OC1B, 8-bit Fast PWM, 62.5 kHz carrier -> RC filter -> out
 */

#include <stdio.h>
#include <stdlib.h>
#include <string.h>

// ─── Buffer ───────────────────────────────────────────────────────────────
#define BUF_SIZE   512
#define BUF_MASK  (BUF_SIZE - 1)
#define S_MIN    (-512)
#define S_MAX      511

// ─── Effect IDs ───────────────────────────────────────────────────────────
#define FX_CLEAN     0
#define FX_OVERDRIVE 1
#define FX_DELAY     2
#define FX_CHORUS    3
#define FX_REVERB    4
#define FX_TUNER     5   // clean passthrough + fundamental-pitch detection

// ─── Parameter bank (written by loop(), read by ISR) ──────────────────────
struct Params {
  uint8_t  effect;    // FX_*
  int16_t  thresh;    // overdrive: clip threshold (1..511)
  uint16_t delayLen;  // delay: tap distance in samples (1..512)
  uint8_t  feedback;  // delay/reverb: regeneration Q8 (0..255)
  uint8_t  mix;       // delay/reverb: wet level Q8 (0..255)
  uint8_t  depth;     // chorus: LFO modulation depth in samples (1..48)
  uint8_t  rate;      // chorus: LFO phase increment per sample (1..20)
};

volatile Params P = {
  FX_CLEAN,
  180,   // thresh    (drive level: 16=breakup, 180=rock, 480=metal)
  400,   // delayLen  (~41.6 ms at 9615 Hz — perceptible slapback)
  190,   // feedback
  220,   // mix
  24,    // depth
  8,     // rate  (~0.85 Hz LFO at 9615 Hz, same feel as rate=4 at 19230 Hz)
};

// ─── Shared audio ring buffer ─────────────────────────────────────────────
static int8_t   audioBuf[BUF_SIZE];
static uint16_t wIdx = 0;

// ─── Chorus LFO ───────────────────────────────────────────────────────────
static uint16_t lfoPhase = 0;

// ─── Telemetry / VGA ──────────────────────────────────────────────────────
volatile int16_t g_peak  = 0;
volatile uint8_t g_clip  = 0;
uint16_t         g_rxErr = 0;
bool             g_autoVGA = true;

// ─── Tuner ────────────────────────────────────────────────────────────────
// Detected fundamental in deci-Hz (Hz x 10); 0 = no pitch / not in tuner mode.
volatile uint16_t g_freqDeciHz = 0;

// ═══════════════════════════════════════════════════════════════════════════
//  processEffect — called from ADC ISR, one sample per call (~52 µs budget)
// ═══════════════════════════════════════════════════════════════════════════
static inline uint16_t processEffect(uint16_t in) {
  int16_t x = (int16_t)in - 512;   // 10-bit unsigned -> signed, centred at 0
  int16_t y = x;

  switch (P.effect) {

    // ── 1. Overdrive ────────────────────────────────────────────────────
    // Pre-amplify then hard-clip at full scale. thresh/16 is the gain factor:
    // thresh=16 -> 1x (just at breakup), thresh=180 -> 11x (rock/metal),
    // thresh=480 -> 30x (extreme saturation, near square wave).
    case FX_OVERDRIVE: {
      int32_t driven = (int32_t)x * P.thresh >> 4;
      if      (driven > S_MAX) { y = S_MAX; g_clip = 1; }
      else if (driven < S_MIN) { y = S_MIN; g_clip = 1; }
      else                       y = (int16_t)driven;
      break;
    }

    // ── 2. Delay ────────────────────────────────────────────────────────
    // Circular-buffer echo. Buffer stores input + feedback*echo;
    // output mixes dry + mix*echo.
    case FX_DELAY: {
      uint16_t dlen = P.delayLen;
      int16_t echo  = (int16_t)audioBuf[(wIdx - dlen) & BUF_MASK] << 2;

      int32_t outv  = (int32_t)x + (((int32_t)echo * P.mix)      >> 8);
      int32_t store = (int32_t)x + (((int32_t)echo * P.feedback)  >> 8);
      if (store > S_MAX) store = S_MAX;
      if (store < S_MIN) store = S_MIN;

      audioBuf[wIdx] = (int8_t)(store >> 2);
      wIdx = (wIdx + 1) & BUF_MASK;

      if (outv > S_MAX) outv = S_MAX;
      if (outv < S_MIN) outv = S_MIN;
      y = (int16_t)outv;
      break;
    }

    // ── 3. Chorus ───────────────────────────────────────────────────────
    // Triangle LFO sweeps the read tap between 48 and (48+depth) samples
    // behind the write head. Dry and wet mixed 50/50; no feedback path.
    case FX_CHORUS: {
      uint8_t tri = (lfoPhase < 32768u)
                    ? (uint8_t)(lfoPhase >> 7)
                    : (uint8_t)((65535u - lfoPhase) >> 7);
      lfoPhase += P.rate;

      uint16_t tapDist = 48u + (((uint16_t)tri * P.depth) >> 8);
      int16_t wet = (int16_t)audioBuf[(wIdx - tapDist) & BUF_MASK] << 2;

      audioBuf[wIdx] = (int8_t)(x >> 2);
      wIdx = (wIdx + 1) & BUF_MASK;

      y = (x >> 1) + (wet >> 1);
      break;
    }

    // ── 4. Reverb ───────────────────────────────────────────────────────
    // Ten equal-weight taps spanning 7.6–50.7 ms at 9615 Hz.
    // Equal weights (each 1/8, computed as sum>>3) create a dense reflection
    // pattern rather than 5 discrete echoes — this is what makes it sound
    // like reverb instead of EQ coloring.
    // Stability: loop gain = 10 * (1/8) * feedback/256 < 1 → feedback < 205.
    // Default feedback=190 gives ~300 ms half-life (medium room).
    case FX_REVERB: {
      int16_t t1  = (int16_t)audioBuf[(wIdx -  73u) & BUF_MASK] << 2;
      int16_t t2  = (int16_t)audioBuf[(wIdx -  97u) & BUF_MASK] << 2;
      int16_t t3  = (int16_t)audioBuf[(wIdx - 127u) & BUF_MASK] << 2;
      int16_t t4  = (int16_t)audioBuf[(wIdx - 163u) & BUF_MASK] << 2;
      int16_t t5  = (int16_t)audioBuf[(wIdx - 211u) & BUF_MASK] << 2;
      int16_t t6  = (int16_t)audioBuf[(wIdx - 271u) & BUF_MASK] << 2;
      int16_t t7  = (int16_t)audioBuf[(wIdx - 337u) & BUF_MASK] << 2;
      int16_t t8  = (int16_t)audioBuf[(wIdx - 397u) & BUF_MASK] << 2;
      int16_t t9  = (int16_t)audioBuf[(wIdx - 457u) & BUF_MASK] << 2;
      int16_t t10 = (int16_t)audioBuf[(wIdx - 487u) & BUF_MASK] << 2;
      int16_t rev = (int16_t)(
        ((int32_t)t1+t2+t3+t4+t5+t6+t7+t8+t9+t10) >> 3);

      int32_t store = (int32_t)x + (((int32_t)rev * P.feedback) >> 8);
      if (store > S_MAX) store = S_MAX;
      if (store < S_MIN) store = S_MIN;
      audioBuf[wIdx] = (int8_t)(store >> 2);
      wIdx = (wIdx + 1) & BUF_MASK;

      int32_t outv = (int32_t)x + (((int32_t)rev * P.mix) >> 8);
      if (outv > S_MAX) outv = S_MAX;
      if (outv < S_MIN) outv = S_MIN;
      y = (int16_t)outv;
      break;
    }

    // ── 5. Tuner ──────────────────────────────────────────────────────────
    // Audible output is clean passthrough (y = x); meanwhile the raw signal is
    // logged into the ring buffer so loop() can run AMDF pitch detection on it.
    case FX_TUNER: {
      audioBuf[wIdx] = (int8_t)(x >> 2);
      wIdx = (wIdx + 1) & BUF_MASK;
      // y stays = x (clean)
      break;
    }
  }

  // Track post-effect peak so AGC responds to what the listener actually hears
  int16_t ay = (y < 0) ? -y : y;
  if (ay > g_peak) g_peak = ay;

  int16_t out = y + 512;
  if (out > 1023) out = 1023;
  if (out < 0)    out = 0;
  return (uint16_t)out;
}

// ═══════════════════════════════════════════════════════════════════════════
//  setup
// ═══════════════════════════════════════════════════════════════════════════
void setup() {
  pinMode(A0, INPUT);
  pinMode(10, OUTPUT);   // audio PWM out (OC1B)
  pinMode( 9, OUTPUT);   // VGA PWM out   (OC1A)

  Serial.begin(115200);
  Serial.println(F("SF4 DSP v2  [0=clean 1=overdrive 2=delay 3=chorus 4=reverb 5=tuner]"));
  Serial.println(F("  e<0-5>    select effect           x         bypass"));
  Serial.println(F("  c<16-511> overdrive drive          v<0|1>    auto-VGA"));
  Serial.println(F("  d<1-512>  delay samples           g<0-255>  manual gain"));
  Serial.println(F("  f<0-255>  feedback / decay"));
  Serial.println(F("  m<0-255>  wet mix"));
  Serial.println(F("  r<1-48>   chorus depth (samples)"));
  Serial.println(F("  s<1-20>   chorus LFO rate"));
  Serial.println(F("  P,e,drv,dl,fb,mix,dp,rt,av,gain  atomic set-all (gain<0=keep)"));
  Serial.println(F("Telemetry: T,effect,peak,vga,clip,rxErr,freqDeciHz (freq in tuner mode)"));

  // ADC: free-running on A0, interrupt on completion, prescaler 128 -> ~9.6 kHz
  ADMUX  = (1 << REFS0);
  ADCSRB = 0;
  DIDR0  = (1 << ADC0D);
  ADCSRA = (1 << ADEN) | (1 << ADATE) | (1 << ADIE)
         | (1 << ADPS2) | (1 << ADPS1) | (1 << ADPS0)
         | (1 << ADSC);

  // Timer1: Mode 5 (8-bit Fast PWM), no prescaler -> 62.5 kHz carrier
  TCCR1A = (1 << COM1A1) | (1 << COM1B1) | (1 << WGM10);
  TCCR1B = (1 << WGM12)  | (1 << CS10);
  OCR1B  = 128;
  OCR1A  =  15;
  TIMSK1 =   0;
}

// ═══════════════════════════════════════════════════════════════════════════
//  Command handler
// ═══════════════════════════════════════════════════════════════════════════
static void handleCmd(char cmd, const char *arg) {
  long v = atol(arg);
  switch (cmd) {

    case 'e': {
      uint8_t fx = (uint8_t)constrain(v, FX_CLEAN, FX_TUNER);
      noInterrupts();
      memset(audioBuf, 0, sizeof(audioBuf));
      wIdx = 0; lfoPhase = 0;
      P.effect = fx;
      interrupts();
      Serial.print(F(">> effect   = ")); Serial.println(fx);
      break;
    }
    case 'c':
      noInterrupts(); P.thresh   = (int16_t)constrain(v, 1, 511);       interrupts();
      Serial.print(F(">> thresh   = ")); Serial.println(P.thresh);   break;
    case 'd':
      noInterrupts(); P.delayLen = (uint16_t)constrain(v, 1, BUF_SIZE); interrupts();
      Serial.print(F(">> delayLen = ")); Serial.println(P.delayLen); break;
    case 'f':
      noInterrupts(); P.feedback = (uint8_t)constrain(v, 0, 255);       interrupts();
      Serial.print(F(">> feedback = ")); Serial.println(P.feedback); break;
    case 'm':
      noInterrupts(); P.mix      = (uint8_t)constrain(v, 0, 255);       interrupts();
      Serial.print(F(">> mix      = ")); Serial.println(P.mix);      break;
    case 'r':
      noInterrupts(); P.depth    = (uint8_t)constrain(v, 1, 48);        interrupts();
      Serial.print(F(">> depth    = ")); Serial.println(P.depth);    break;
    case 's':
      noInterrupts(); P.rate     = (uint8_t)constrain(v, 1, 20);        interrupts();
      Serial.print(F(">> rate     = ")); Serial.println(P.rate);     break;
    case 'v':
      g_autoVGA = (v != 0);
      Serial.print(F(">> autoVGA  = ")); Serial.println(g_autoVGA ? F("ON") : F("OFF")); break;
    case 'g':
      OCR1A = (uint8_t)constrain(v, 0, 255);
      g_autoVGA = false;
      Serial.print(F(">> VGA gain = ")); Serial.println(OCR1A);     break;
    case 'x':
      noInterrupts();
      memset(audioBuf, 0, sizeof(audioBuf));
      wIdx = 0; lfoPhase = 0;
      P.effect = FX_CLEAN;
      interrupts();
      Serial.println(F(">> bypass (clean)"));                         break;

    // ── Atomic set-all frame (host link) ─────────────────────────────────
    // P,<effect>,<drive>,<delayLen>,<feedback>,<mix>,<depth>,<rate>,<autoVGA>,<gain>
    // Applies the whole parameter bank in one cli/sei section so the ISR never
    // reads a half-updated mix of old + new values. gain < 0 leaves the VGA
    // (and auto-VGA mode) untouched; gain >= 0 sets manual gain + auto-VGA off.
    case 'P': {
      int e, drv, dl, fb, mx, dp, rt, av, gn;
      if (sscanf(arg, ",%d,%d,%d,%d,%d,%d,%d,%d,%d",
                 &e, &drv, &dl, &fb, &mx, &dp, &rt, &av, &gn) != 9) {
        g_rxErr++;
        break;
      }
      uint8_t  fx       = (uint8_t)constrain(e,   FX_CLEAN, FX_TUNER);
      int16_t  thresh   = (int16_t)constrain(drv, 1, 511);
      uint16_t delayLen = (uint16_t)constrain(dl, 1, BUF_SIZE);
      uint8_t  feedback = (uint8_t)constrain(fb,  0, 255);
      uint8_t  mix      = (uint8_t)constrain(mx,  0, 255);
      uint8_t  depth    = (uint8_t)constrain(dp,  1, 48);
      uint8_t  rate     = (uint8_t)constrain(rt,  1, 20);

      noInterrupts();
      memset(audioBuf, 0, sizeof(audioBuf));   // effect may change → clear history
      wIdx = 0; lfoPhase = 0;
      P.effect   = fx;
      P.thresh   = thresh;
      P.delayLen = delayLen;
      P.feedback = feedback;
      P.mix      = mix;
      P.depth    = depth;
      P.rate     = rate;
      interrupts();

      if (gn >= 0) {                            // explicit manual gain
        OCR1A = (uint8_t)constrain(gn, 0, 255);
        g_autoVGA = false;
      } else {                                  // -1 sentinel: honour autoVGA flag
        g_autoVGA = (av != 0);
      }
      Serial.print(F(">> set effect=")); Serial.print(fx);
      Serial.print(F(" drive="));        Serial.print(thresh);
      Serial.print(F(" autoVGA="));      Serial.println(g_autoVGA ? F("ON") : F("OFF"));
      break;
    }

    default:
      g_rxErr++;
      break;
  }
}

// ═══════════════════════════════════════════════════════════════════════════
//  Tuner — AMDF pitch detection (runs in loop(), never the ISR)
// ═══════════════════════════════════════════════════════════════════════════
//  D(tau) = sum_{n=0..WIN-1} | buf[i-n] - buf[i-n-tau] |  is minimised over the
//  guitar lag range. The deepest dip is the fundamental period; parabolic
//  interpolation around it recovers sub-sample resolution (essential for the
//  high strings, where one whole-sample step is tens of cents at FS 9615 Hz).
#define TUNER_TAU_MIN  24     // ~400 Hz upper search bound
#define TUNER_TAU_MAX  128    // ~75 Hz lower search bound
#define TUNER_WIN      256    // comparison window length in samples
#define TUNER_SPAN    (TUNER_WIN + TUNER_TAU_MAX)  // samples the AMDF reaches back
#define TUNER_NOISE    12     // post-effect peak below this = treat as silence
#define FS_HZ          9615.0f

// The detector works on a frozen copy of the most recent TUNER_SPAN samples.
// Copying out of the live ring first is essential: the ISR keeps writing at
// ~9.6 kHz, so an in-place AMDF (tens of ms) would read samples that get
// overwritten mid-computation and smear the result.
static int8_t tunerSnap[TUNER_SPAN];   // tunerSnap[0] = newest, [k] = k samples older

// AMDF for one lag over the frozen snapshot (plain linear indexing).
static uint32_t amdf(uint16_t tau) {
  uint32_t d = 0;
  for (uint16_t n = 0; n < TUNER_WIN; n++) {
    int16_t diff = (int16_t)tunerSnap[n] - (int16_t)tunerSnap[n + tau];
    d += (diff < 0) ? (uint16_t)(-diff) : (uint16_t)diff;
  }
  return d;
}

static void detectPitch() {
  noInterrupts();
  int16_t peak = g_peak;
  interrupts();
  if (peak < TUNER_NOISE) { g_freqDeciHz = 0; return; }   // nothing plucked

  // Freeze the window: copy newest-first from the ring. ~384 byte reads finish
  // in well under one sample period of drift, so the snapshot is coherent.
  uint16_t i = wIdx;
  for (uint16_t k = 0; k < TUNER_SPAN; k++)
    tunerSnap[k] = audioBuf[(uint16_t)(i - 1 - k) & BUF_MASK];

  uint32_t bestD = 0xFFFFFFFFUL, sumD = 0;
  uint16_t bestTau = 0, count = 0;

  for (uint16_t tau = TUNER_TAU_MIN; tau <= TUNER_TAU_MAX; tau++, count++) {
    uint32_t d = amdf(tau);
    sumD += d;
    if (d < bestD) { bestD = d; bestTau = tau; }
  }

  // Reject if the dip isn't clearly below the mean (unvoiced / noisy), or if it
  // landed on a search boundary (can't interpolate / likely out of range).
  uint32_t mean = sumD / count;
  if (bestD * 2 > mean || bestTau <= TUNER_TAU_MIN || bestTau >= TUNER_TAU_MAX) {
    g_freqDeciHz = 0;
    return;
  }

  // Parabolic interpolation around the minimum for a sub-sample period.
  float d0 = (float)amdf(bestTau - 1);
  float d1 = (float)bestD;
  float d2 = (float)amdf(bestTau + 1);
  float denom = d0 - 2.0f * d1 + d2;
  float delta = (denom > 0.0f) ? 0.5f * (d0 - d2) / denom : 0.0f;
  float tauR  = (float)bestTau + delta;

  float f = FS_HZ / tauR;
  g_freqDeciHz = (uint16_t)(f * 10.0f + 0.5f);
}

// ═══════════════════════════════════════════════════════════════════════════
//  Main loop — serial parser + VGA
// ═══════════════════════════════════════════════════════════════════════════
void loop() {
  static char    line[48];   // wide enough for the atomic 'P' set-all frame
  static uint8_t llen = 0;

  // Serial command parser
  while (Serial.available()) {
    char ch = (char)Serial.read();
    if (ch == '\n' || ch == '\r') {
      if (llen > 0) {
        line[llen] = '\0';
        char *p = line;
        while (*p == ' ') p++;
        if (*p) handleCmd(*p, p + 1);
        llen = 0;
      }
    } else if (llen < (uint8_t)(sizeof(line) - 1)) {
      line[llen++] = ch;
    }
  }

  uint32_t now = millis();
  static uint32_t lastVGA   = 0;
  static uint32_t lastTelem = 0;
  static uint32_t lastTuner = 0;
  static int16_t  telemPeak = 0;

  // ── Tuner pitch detection (every 150 ms, tuner mode only) ───────────────
  if (P.effect == FX_TUNER) {
    if (now - lastTuner >= 150) { lastTuner = now; detectPitch(); }
  } else {
    g_freqDeciHz = 0;
  }

  // ── VGA loop (every 15 ms) ──────────────────────────────────────────────
  // One OCR1A step per tick: smooth gain rides with no pumping.
  // Noise floor guard prevents boosting silence into audible hiss.
  if (now - lastVGA >= 15) {
    lastVGA = now;

    noInterrupts();
    int16_t peak = g_peak;
    g_peak = 0;
    interrupts();

    if (peak > telemPeak) telemPeak = peak;

    if (g_autoVGA) {
      const int16_t VGA_HIGH  = 380;   // reduce gain above this peak
      const int16_t VGA_LOW   =  40;   // boost gain below this peak
      const int16_t VGA_NOISE =   8;   // silence floor — never boost below
      const uint8_t VGA_DEF   =  15;   // resting OCR1A (sweet-spot gain)
      const uint8_t VGA_MAX   =  80;   // max attenuation ceiling

      if (peak > VGA_HIGH) {
        if (OCR1A < VGA_MAX) OCR1A++;          // too loud  → step gain down
      } else if (peak > VGA_NOISE && peak < VGA_LOW) {
        if (OCR1A > 0)       OCR1A--;          // too quiet → step gain up
      } else {
        if      (OCR1A > VGA_DEF) OCR1A--;     // in range / silent → drift to resting
        else if (OCR1A < VGA_DEF) OCR1A++;
      }
    }
  }

  // ── Telemetry (every 100 ms) ────────────────────────────────────────────
  if (now - lastTelem >= 100) {
    lastTelem = now;
    uint8_t  clip;
    uint16_t freq;
    noInterrupts(); clip = g_clip; g_clip = 0; freq = g_freqDeciHz; interrupts();

    Serial.print(F("T,")); Serial.print(P.effect);
    Serial.print(',');      Serial.print(telemPeak);
    Serial.print(',');      Serial.print(OCR1A);
    Serial.print(',');      Serial.print(clip);
    Serial.print(',');      Serial.print(g_rxErr);
    Serial.print(',');      Serial.println(freq);

    telemPeak = 0;
  }
}

// ═══════════════════════════════════════════════════════════════════════════
//  ADC ISR — fires at ~9.6 kHz
// ═══════════════════════════════════════════════════════════════════════════
ISR(ADC_vect) {
  OCR1B = (uint8_t)(processEffect(ADC) >> 2);
}

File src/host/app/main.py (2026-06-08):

"""
FastAPI app: owns the serial link + authoritative amp state, serves the two-panel
web UI, and exposes the manual / chat / telemetry endpoints.

Run from src/host/:
    ANTHROPIC_API_KEY=...  uvicorn app.main:app --reload
    (set SF4_PORT to force a serial port; otherwise it auto-detects, and falls
     back to a mock board if none is found)
"""

from __future__ import annotations

import asyncio
import io
import json
import os
import threading
from contextlib import asynccontextmanager
from pathlib import Path

try:
    from dotenv import load_dotenv
    load_dotenv()  # load src/host/.env (ANTHROPIC_API_KEY, SF4_MODEL, SF4_PORT)
except ImportError:
    pass

from fastapi import FastAPI, File, HTTPException, UploadFile
from fastapi.responses import FileResponse, StreamingResponse
from fastapi.staticfiles import StaticFiles

from .models import AmpParams, ChatRequest
from .serial_link import create_link
from .tone_engine import ToneEngine

STATIC_DIR = Path(__file__).parent / "static"


def _dump(p: AmpParams) -> dict:
    """Serialise params with `effect` as its name (clean/overdrive/...) for the UI."""
    d = p.model_dump()
    d["effect"] = p.effect.name.lower()
    return d


@asynccontextmanager
async def lifespan(app: FastAPI):
    app.state.link = create_link(os.environ.get("SF4_PORT"))
    app.state.params = AmpParams()
    app.state.lock = threading.Lock()
    try:
        app.state.engine = ToneEngine()
    except Exception as exc:                      # no key / SDK / etc.
        print(f"[tone_engine] chat disabled: {exc}")
        app.state.engine = None
    # Push the default state to the board so hardware matches the UI on boot.
    try:
        app.state.link.apply(app.state.params)
    except Exception:
        pass
    yield
    app.state.link.close()


app = FastAPI(title="SF4 Smart Guitar Amp", lifespan=lifespan)


def apply_params(p: AmpParams) -> AmpParams:
    """The single path both panels funnel through: write to MCU + update state."""
    with app.state.lock:
        app.state.link.apply(p)
        app.state.params = p
        return p


@app.get("/api/state")
def get_state():
    return _dump(app.state.params)


@app.post("/api/params")
def set_params(params: AmpParams):
    """Manual control panel: apply a full parameter set (no LLM)."""
    return _dump(apply_params(params))


@app.post("/api/chat")
def chat(req: ChatRequest):
    """Chat panel: one conversational turn; may change the sound via the tool."""
    engine: ToneEngine | None = app.state.engine
    if engine is None:
        raise HTTPException(503, "Chat is unavailable: set ANTHROPIC_API_KEY and "
                                 "install the anthropic SDK, then restart.")
    tel = app.state.link.get_telemetry()
    try:
        reply, params, changed = engine.chat(
            message=req.message,
            history=req.history,
            current=app.state.params,
            apply_fn=apply_params,
            telemetry=tel,
        )
    except Exception as exc:
        raise HTTPException(502, f"LLM error: {exc}")
    return {"reply": reply, "params": _dump(params), "changed": changed}


@app.post("/api/transcribe")
async def transcribe(audio: UploadFile = File(...)):
    """Voice input: receive a recorded audio blob, return Whisper transcription."""
    api_key = os.environ.get("OPENAI_API_KEY")
    if not api_key:
        raise HTTPException(503, "OPENAI_API_KEY not set — voice input unavailable.")
    try:
        import openai
        data = await audio.read()
        buf = io.BytesIO(data)
        buf.name = audio.filename or "recording.webm"
        result = openai.OpenAI(api_key=api_key).audio.transcriptions.create(
            model="whisper-1", file=buf
        )
        return {"text": result.text}
    except Exception as exc:
        raise HTTPException(502, f"Transcription error: {exc}")


@app.get("/api/telemetry")
async def telemetry():
    """Server-Sent Events: live telemetry at ~10 Hz."""

    async def gen():
        while True:
            tel = app.state.link.get_telemetry()
            payload = tel.to_dict()
            payload["connected"] = app.state.link.connected
            payload["port"] = app.state.link.port
            yield f"data: {json.dumps(payload)}\n\n"
            await asyncio.sleep(0.1)

    return StreamingResponse(gen(), media_type="text/event-stream")


@app.get("/")
def index():
    return FileResponse(STATIC_DIR / "index.html")


# Static assets (app.js, style.css). Mounted last so /api/* takes precedence.
app.mount("/static", StaticFiles(directory=STATIC_DIR), name="static")

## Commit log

2026-05-22 Input buffer ltspice schematic
2026-05-22 gitignore configuration and schematics directory setup
2026-05-23 filter stage LTSpice schematics
2026-05-24 Full Circuit
    [lmx58_lm2904.dsn]
2026-05-24 all 3 stage integrated to full circuit schematic
2026-05-25 Full circuit KiCad schematics
    [SF4.kicad_pcb, SF4.kicad_sch]
2026-05-25 flattend KiCad directory
    [SF4.kicad_pcb, SF4.kicad_sch]
2026-05-26 LTSpice schematics and simulation figures
2026-06-02 Optocoupler performance tested
    [SF4.kicad_sch]
2026-06-07 Build the host-side software for the SF4 smart guitar amp and add the matching firmware command.
    - firmware: atomic 'P' set-all serial frame for glitch-free preset apply
    - host: FastAPI app owning the serial link + amp state; conversational
    Claude tone engine (set_amp_params tool, model-aware thinking) with a
    mock link for no-hardware use; two-panel web UI — manual rotary-knob
    control + chat — with live SSE telemetry, in a boutique-amp visual style
    - automation: Makefile, requirements.txt, .env config (gitignored)
    - docs: rewrite stale host/firmware READMEs to the current 5-effect protocol
    [DSP_Pipeline.ino, main.py, models.py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]
2026-06-09 demo video attached
2026-07-04 update readme and added output data
    [SF4.kicad_pcb, SF4.kicad_sch, lmx58_lm2904.dsn]
